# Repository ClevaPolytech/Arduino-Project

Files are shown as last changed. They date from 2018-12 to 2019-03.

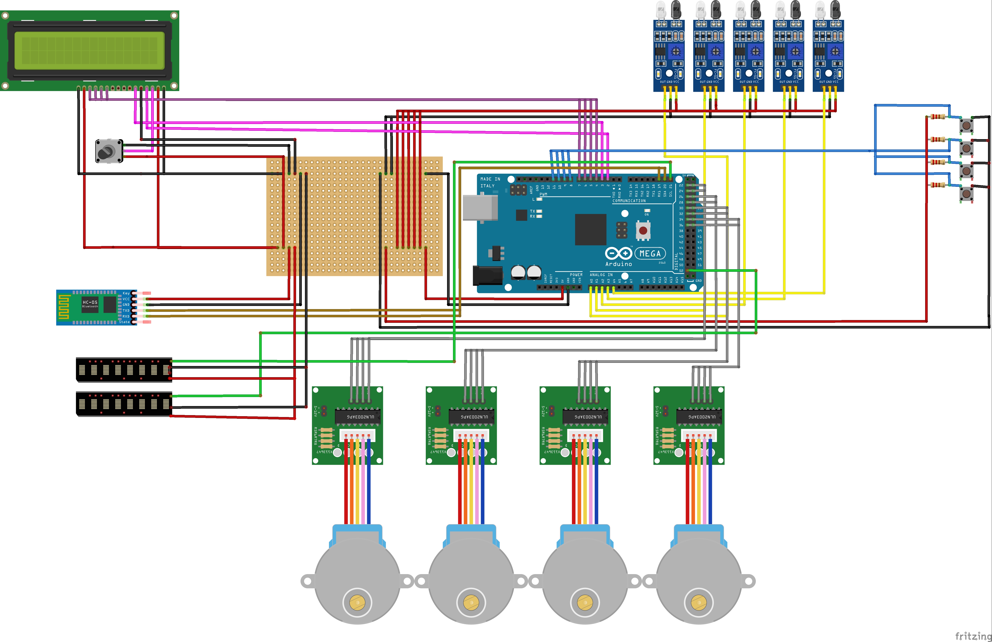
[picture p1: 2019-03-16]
CodesProjets/Montage/schemaFFcomplet.jpg

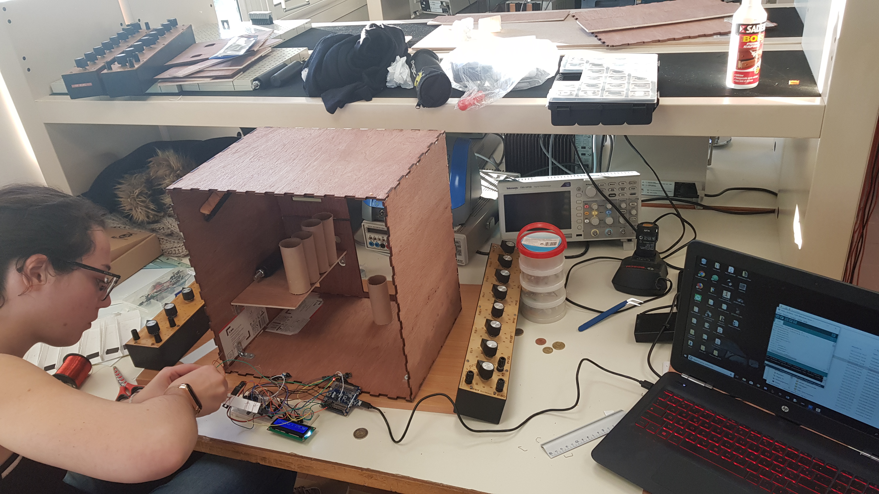
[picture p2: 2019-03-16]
Photos/20190107_161705.jpg

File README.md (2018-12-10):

## Welcome to GitHub Pages

You can use the [editor on GitHub](https://github.com/ClevaPolytech/Arduino-Project/edit/master/README.md) to maintain and preview the content for your website in Markdown files.

Whenever you commit to this repository, GitHub Pages will run [Jekyll](https://jekyllrb.com/) to rebuild the pages in your site, from the content in your Markdown files.

### Markdown

Markdown is a lightweight and easy-to-use syntax for styling your writing. It includes conventions for

```markdown
Syntax highlighted code block

# Header 1
## Header 2
### Header 3

- Bulleted
- List

1. Numbered
2. List

**Bold** and _Italic_ and `Code` text

[Link](url) and ![Image](src)
```

For more details see [GitHub Flavored Markdown](https://guides.github.com/features/mastering-markdown/).

### Jekyll Themes

Your Pages site will use the layout and styles from the Jekyll theme you have selected in your [repository settings](https://github.com/ClevaPolytech/Arduino-Project/settings). The name of this theme is saved in the Jekyll `_config.yml` configuration file.

### Support or Contact

Having trouble with Pages? Check out our [documentation](https://help.github.com/categories/github-pages-basics/) or [contact support](https://github.com/contact) and we’ll help you sort it out.

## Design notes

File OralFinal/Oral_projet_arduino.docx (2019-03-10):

Oral projet arduino

-Intro : Maev

-Qu’est-ce que c’est ?

D’où vient l’idée : idée de Maeva tirelire + volonté de clément de réaliser un objet utile, plus imposant.

C’est un distributeur de nourriture avec monnayeur intégré et ne rend pas la monnaie.

-Monnayeur

-Lumière/barre de chargement

-écran lcd pour les informations

- boutons de sélection

Objectifs

-pour but de faire un projet pas compliqué mais finissable, projet achevable dans le temps imparti.

-Nous souhaitons faire un distributeur automatique de petits objets. On se base sur le principe des distributeurs de nourriture, comme on peut en trouver un peu partout.

Comment va-t-on procéder :

• Faire la structure (une sorte de boîte de dimension : 30x40x40 (largeur, longueur, hauteur))

• Faire un monnayeur qui compte la monnaie (si jamais on a le temps on fait un rendu de monnaie)

• Un écran LCD qui indique la somme mise dans la machine

• Des boutons pour choisir l’objet

• Un système de « paiement par carte » qui reviendrait à envoyer une information par Bluetooth

- Un système de sécurité pour ouvrir la porte qui dévoile le mécanisme

• Une trappe qui s’ouvre pour pouvoir récupérer l’objet

En bonus (si on a le temps)

• Machine à café

• Rendre la monnaie

-Evolution chronologique :

1ere partie : du début –> assemblage de la boite

-1ere conception autodesk

-tube pq, récup les pièces

-découpe planche de bois

- monnayeur (pièce noire)

-fichier de découpe inkscape + découpe laser

-assemblage des planches

-ressort

Problèmes 1ere partie :

-écart face avant résolu par LED

- problème de dimension découpe laser

- tubes qui se détache

- rail trop grand découpé à plusieurs reprises

2e partie : assemblage boite ->peinture rouge

- Trou face avant, détails (pour l’écran, bouton, fente pièce, récup monnaie)
- Découpe laser FabLab des planches intérieures.
- Rail
- Piece polystyrène monnayeur
- Ecran LCD
- Capteur IR
- Peinture

Problèmes 2e partie :

- Capteur IR avec le soleil +code, solution scotch noir
- Dimensions trous boutons résolu par les LED
- Oubli de la porte donc découpe face avant +charnière.

3e partie : peinture -> fin

- Boutons + nouveaux trous
- Moteurs
- Pieces en bois entre le ressort et le moteur, calle ressort
- Nouvelles LED
- Bluetooth
- Le pvc tordu
- Soudure
- Optimisation
  - Nouveaux ressorts
  - Nouveau rail

Problèmes 3e partie :

- Problème pièce pvc douteuse
- Conception 3D
- Code Moteur
- Moteur bloqué par la pièce en bois, donc ne tourne pas -> solution : moyeux
- Toboggan pas de place

Planning

Planning programmé jusqu’au 14 janvier 2019, planning largement non tenu -> vrai planning

Conclusion

Remerciements

Aux enseignants : Mr Masson, Mr A

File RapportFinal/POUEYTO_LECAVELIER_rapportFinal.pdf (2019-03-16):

Département d partement d’ Electronique lectronique

# PROJETS ARDUINO – PEIP2

## Année scolaire 2018-2019

## Distributeur automatique alimentaire :

## Le PolyShop

### Etudiants : Clément POUEYTO, Maëva LECAVELIER

### Encadrants : Pascal MASSON, Nassim ABDERRAHMANE

Ecole Polytechnique Universitaire de Nice Sophia-Antipolis, Electronique avec ARDUINO 1645 route des Lucioles, Parc de Sophia Antipolis, 06410 BIOT

PeiP2-Electronique avec ARDUINO

### REMERCIEMENTS

Nous tenions à remercier Monsieur Pascal Masson, enseignant-chercheur à Polytech’Nice, pour sa disponibilité, sa patience, sa bienveillance, son investissement et ses conseils. Et, également, l’entreprise SYMES, bureau d’étude électronique à Cagnes sur Mer pour nous avoir prêté leur imprimante 3D. Nous remercions aussi Marc Forner pour son aide lors de nos venues au FabLab.

## SOMMAIRE

## Introduction

Durant cette deuxième année en PeiP de Polytech’Nice, nous avons dû réaliser un projet avec la carte Arduino. Ce projet avait pour but de nous apprendre à créer et à s’adapter aux difficultés que l’on peut rencontrer dans l’élaboration d’un tel objet. Il visait aussi à l’apprentissage et au perfectionnement de l’utilisation des différents outils et logiciels.

Nous avons décidé de faire un distributeur de petits snacks (type Snickers, Tictac, chewing-gum etc…). Ce distributeur prend les pièces de 10cts à 2€, trie les pièces, et distribue de la nourriture. Il ne rend pas la monnaie.

Voici notre projet à l’écriture de ce rapport :

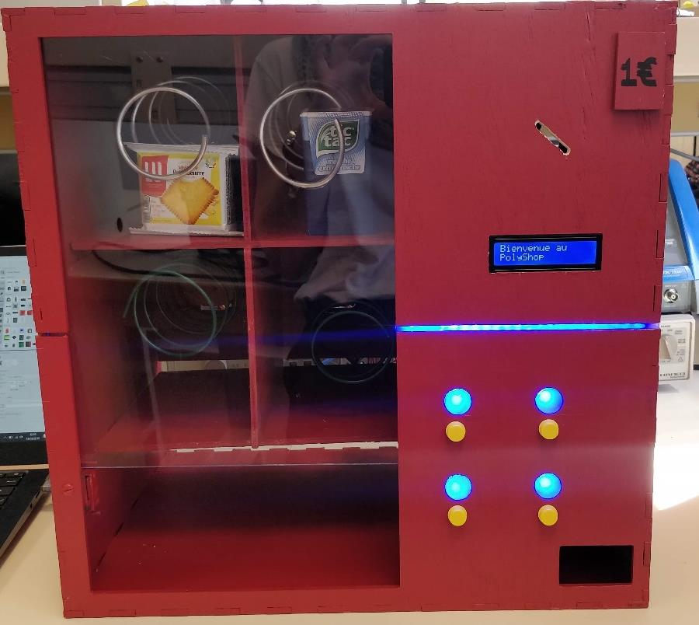
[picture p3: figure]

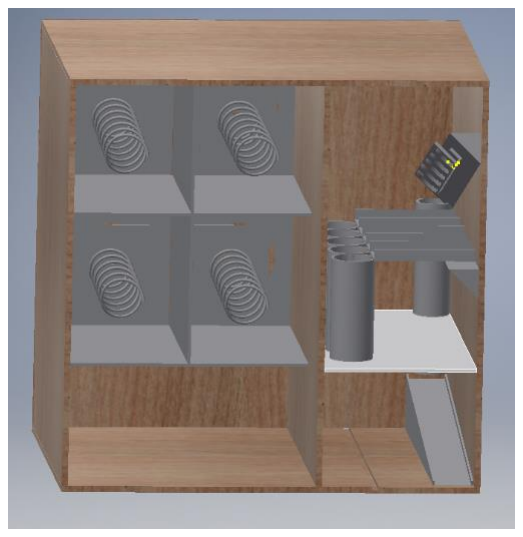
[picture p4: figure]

Fichier 3D sans la façade avant

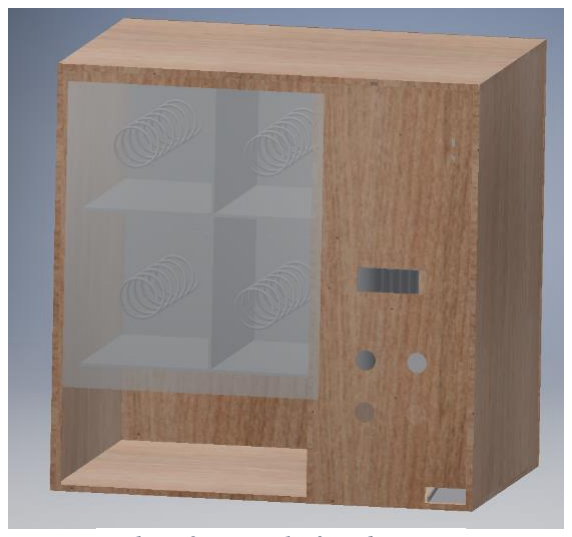
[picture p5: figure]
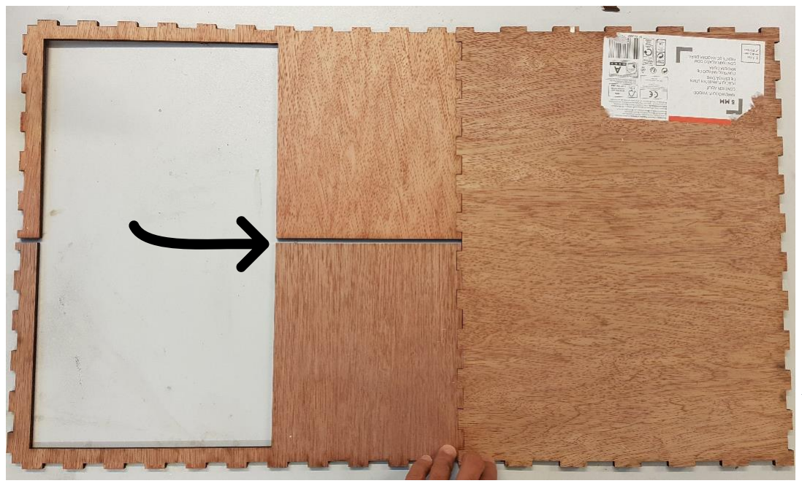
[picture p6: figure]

Planche 40*40 fixée à la planche adjacente. On voit la fente qui pose un problème.

# Chapitre I : La construction du distributeur

### I.1 La modélisation 3D

Dès le début du projet, nous avons représenté en 3D notre objet pour visualiser ce que nous souhaitions. Cette étape nous a permis d’avoir les dimensions de toutes les pièces et planches que nous allions avoir besoin. Le logiciel utilisé est Autodesk Inventor.

Pour ce faire, nous
réalisons les pièces une par
une | pour | ensuite | les
assembler. Certaines pièces ne sont pas forcément bien assemblées avec les autres,
mais | ce | fichier | a
uniquement pour but de
nous renseigner sur les
dimensions, l’agencement et les pièces nécessaires. Cela a été le fil rouge de notre projet.

### I.2 La découpeuse laser et Inkscape

Pour découper les planches extérieures de notre projet, nous avons utilisé une découpeuse laser. Il était nécessaire d’utiliser cet outil, car la découpe devait être précise pour que l’on puisse bien assembler la boîte. Nous nous sommes alors initiés à Inkscape, logiciel professionnel de dessin vectoriel libre et gratuit. Pour représenter notre projet, nous utilisons l’extension Box Maker, téléchargeable depuis le site du logiciel.

Le premier problème que l’on a rencontré était la dimension des planches que l’on peut découper dans la découpeuse laser. Elle n’accepte que des planches de 30*60 cm alors que l’on doit couper des planches de 40*40 cm. Pour réussir malgré cet obstacle, nous avons dû découper les grandes planches en deux fois. Mais un autre problème est survenu, il y avait une fente au milieu lorsque nous avons regroupé toutes les planches. Illustration :

Fichier 3D avec la façade avant

Guirlande de LED intérieur

Guirlande de LED vue de l’extérieur

Notre projet une fois que
les | planches | sont
découpées et assemblées
(non collées encore)

On a résolu ce problème plus tard en mettant une guirlande de LED et une fine plaque de plexiglass gravée à la découpeuse laser pour diffuser la lumière.

Les autres découpes faites avec Inkscape et la découpeuse laser sont celles des trous de la face avant. Il faut des trous pour mettre l’écran, les boutons, la pièce de monnaie et récupérer la monnaie.

La fente pour les pièces de monnaie

La fente pour l’écran LCD

La fente pour les boutons. A cause d’une erreur lors de l’édition du fichier, les trous sont trop grands, pour résoudre le problème on a fixé des ronds de plexiglass gravé avec des LED derrière. Puis, nous avons repercé pour avoir des trous de la bonne dimension.

Le trou pour récupérer les pièces, mais finalement nous n’avons pas eu le temps de faire un système de rendu de monnaie.

### I.3. Les autres pièces

### I.3.1 Les planches internes

Il faut faire des petites planches intérieures qui vont servir à séparer la partie système et visible, supporter la carte Arduino ou encore délimiter les compartiments des différents aliments. Pour celles-ci, nous avons recyclé les chutes des grandes planches et les avons découpées à la scie sauteuse. Pour les fixer, nous avons utilisé de la colle à bois. De plus, les dimensions étaient faites de telle manière que la planche soit serrée entre les grandes planches, comme ça, il était plus facile de coller.

Solution pour mettre les boutons

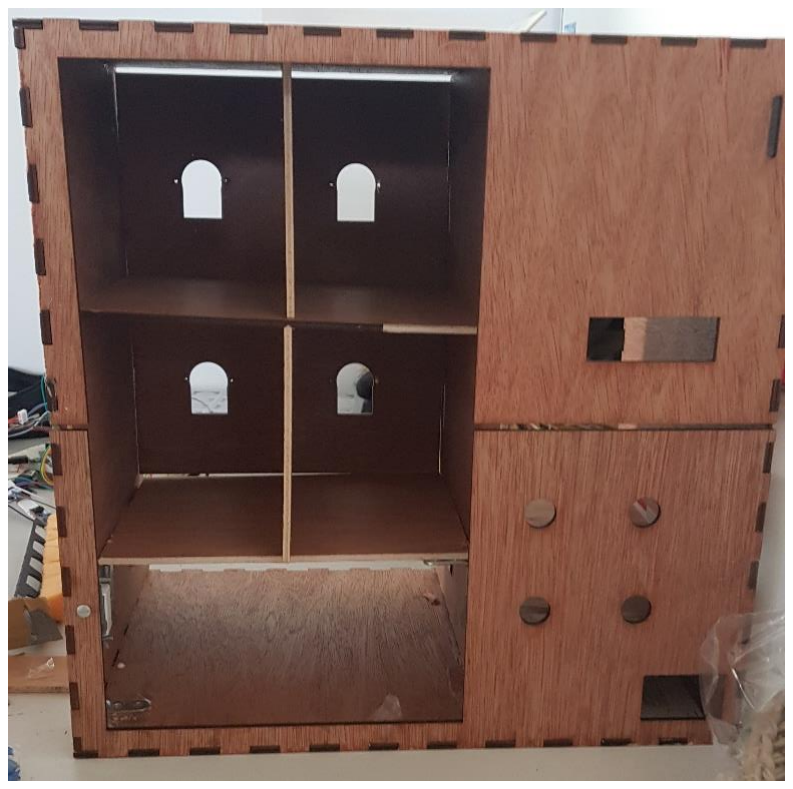
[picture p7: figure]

Vue de face. Derrière les trous il y a la planche qui tiendra le système.

Pour fixer correctement les moteurs, Inkscape nous a encore été utile. Nous avons pris une planche et dedans on a découpé la forme des moteurs. Ce qui donne :

### I.3.2. Le système de tri de pièces

I.3.2.a. Trier les pièces.

Pour réaliser cette partie, on a cherché des idées sur internet. Le tri selon la taille paraissait le meilleur compromis. Donc, nous sommes partis sur cette idée. Mais il y avait une contrainte au niveau de la taille de notre trieur, il ne fallait pas qu’il soit trop long ni trop large. On s’est alors dit que l’on pouvait trier selon le diamètre. A partir d’Autodesk Inventor encore, nous avons modélisé cette pièce :

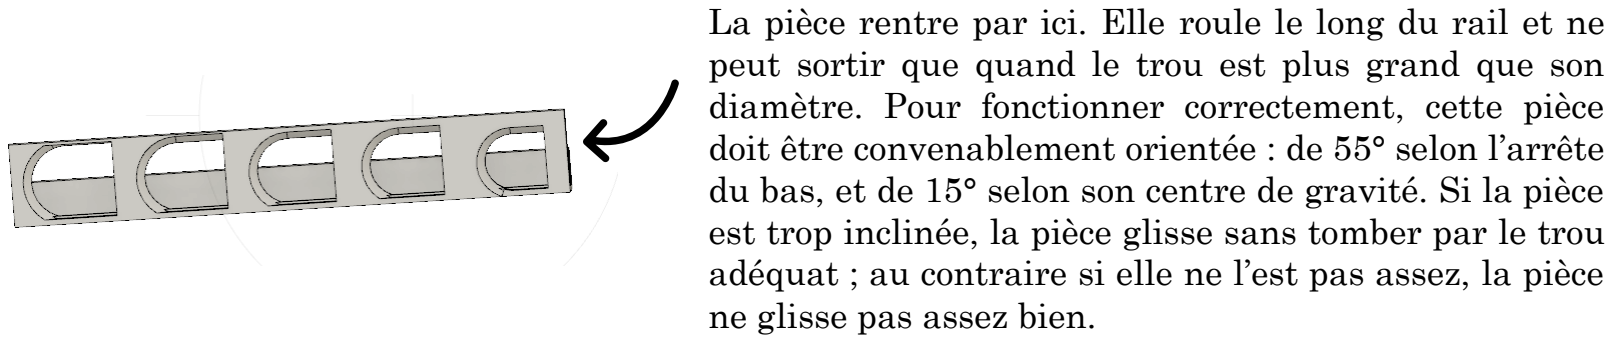
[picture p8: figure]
ne glisse pas assez bien.

Une fois que les pièces sont correctement triées, elle glisse le long d’un rail. Ce rail, d’abord réalisé en bricolant, a été ensuite modélisé et imprimé en 3D. Le système de détection sera expliqué plus tard.

La pièce rentre par ici. Elle roule le long du rail et ne peut sortir que quand le trou est plus grand que son diamètre. Pour fonctionner correctement, cette pièce doit être convenablement orientée : de 55° selon l’arrête du bas, et de 15° selon son centre de gravité. Si la pièce est trop inclinée, la pièce glisse sans tomber par le trou adéquat ; au contraire si elle ne l’est pas assez, la pièce

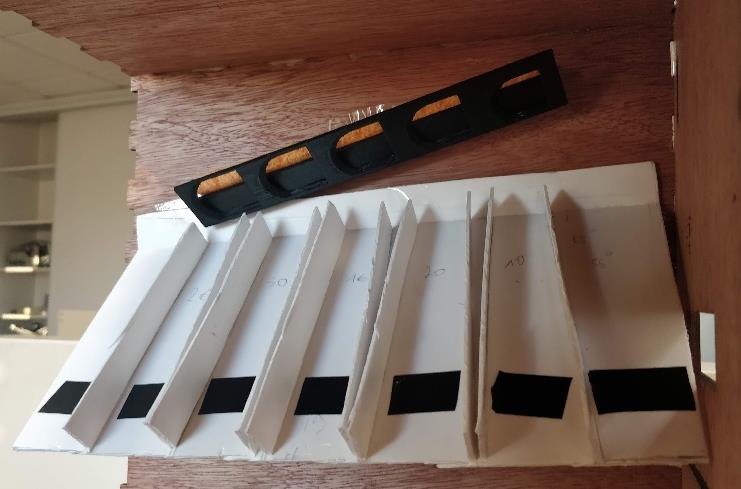
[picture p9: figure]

Ancien modèle en PVC et tenu par du scotch, et trieuse indépendante, correctement fixée grâce à du polystyrène.

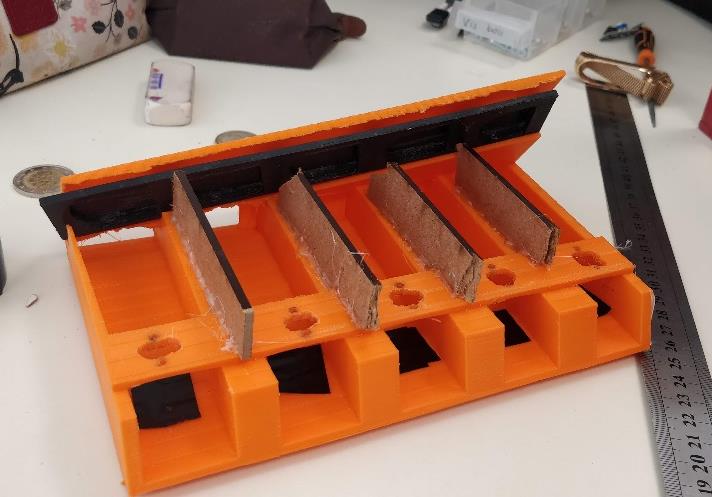
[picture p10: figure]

Nouveau modèle, en 3D, avec support pour la trieuse et pièce en bois pour séparer les compartiments. Elle est surélevée par la suite grâce à des pieds en bois.

I.3.2.b. Stocker les pièces.

Initialement, le stockage des pièces était prévu pour pouvoir rendre la monnaie plus facilement. Mais nous n’avons pas pu développer cette fonctionnalité. Cependant, nous voulons tout de même stocker nos pièces. Le problème est qu’il ne reste plus beaucoup de place dans le compartiment système, et qu’avec
tous les câbles que nous aurons, il sera difficile de retirer
des grosses pièces… Au début, nous avons découpé un tube
en carton en plusieurs petits tubes qui récolteront les pièces. Mais finalement, ceux-ci étaient trop difficiles à
utiliser | correctement | (pour | les | raisons | citées
précédemment), nous avons abandonné l’idée de ces tubes.

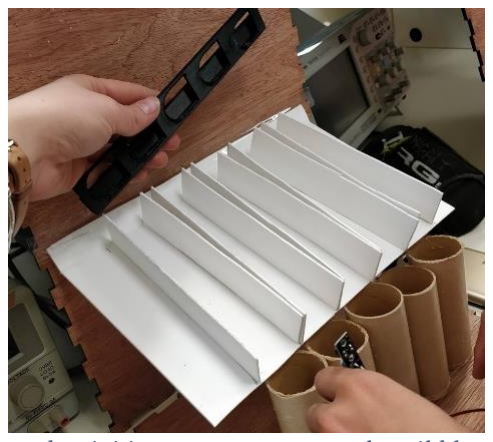
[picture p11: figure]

Comme le rendu de pièce semblait impossible, l’idée d’un rail qui faisait glisser les pièces jusqu’à un récipient, sans séparer les différentes pièces de monnaie, était bien. Mais nous n’avons pas eu le temps d’explorer convenablement cette piste.

### I.4 La distribution des produits

I.4.1. Les vis sans fin.

Comme dans les « vrais » distributeurs, il nous fallait un système de vis sans fin pour faire tomber le produit.

Au début, nous utilisions du fil métallique plastifié que nous avions entouré autour d’une bouteille. Mais, ces vis étaient trop souples, se tordaient, et étaient relativement lourdes. Alors, nous avons
remplacé | le | fil | métallique | par | de
l’aluminium. C’est plus difficile à tordre, mais plus solide et léger. Pour le tordre, nous l’avons enroulé autour d’un tube PVC dans lequel nous avions fait un petit trou pour maintenir la tige en alu.

Les tubes initiaux se trouvent sous le rail blanc.

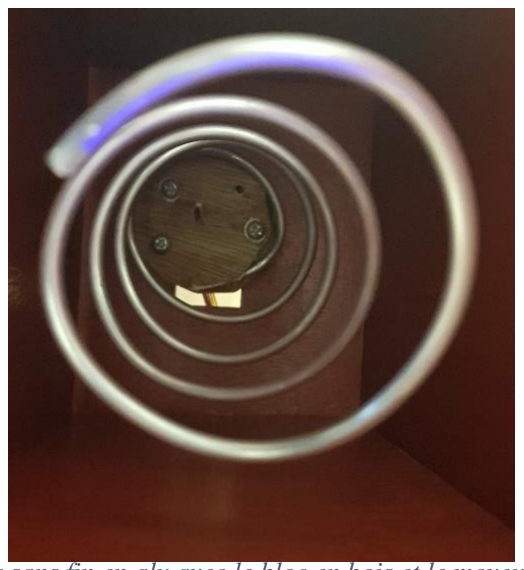
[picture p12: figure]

Vis sans fin en alu avec le bloc en bois et le moyeu (derrière la pièce ronde en bois) fixés au moteur.

I.4.2. Liaison vis-moteur.

Après avoir réalisé les vis sans fin, il faut les relier au moteur. Pour cela, nous avons pris du bois, découpé en rond, puis nous avons « encadré » le bout de la vis sans fin entre deux planches rondes et les avons vissées entre elles pour que ce soit bien fixé. Pour accrocher ce système, nous avons fait un trou de la taille de l’axe du moteur pour pouvoir glisser les vis sans fin dessus. Mais nous avons rencontré plusieurs problèmes :

Les vis utilisées gênaient à la rotation de la pièce en bois : les vis frottaient et le bloc vis+rond en bois tombait.

Après avoir résolu ce premier problème en creusant légèrement dans le bois, le bloc vis+rond tombait tout seul à cause du poids de ce dernier et des mouvements des vis souples.

La seule solution est d’installer des moyeux, pièce qui se coince au moteur grâce à une vis de serrage et qui vient se visser correctement au bloc. Mais leur installation est longue : environ 1h par vis. Donc, actuellement, nous n’en avons qu’un seul d’installé, mais plus tard il faudra couper autour de chaque moteur pour sortir tout le bloc et installer le moyeu en aillant plus de place.

I.5. La façade.

I.5.1. Peinture et personnalisation.

Pour rendre notre distributeur plus beau et cacher les étiquettes et les imperfections du bois, nous avons peint notre projet. Nous voulions une couleur rouge plus ou moins métallisé, mais la peinture que nous avons eu été un rouge basque (un rouge qui tend légèrement vers le rose). Nous avons fait 2 couches de peinture presque partout, sauf dans les endroits difficilement atteignables.

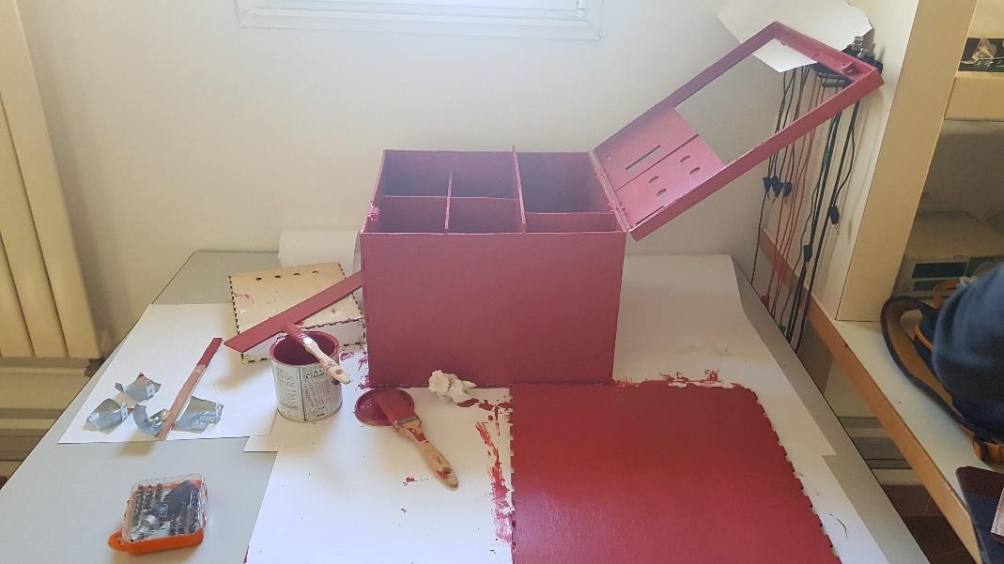
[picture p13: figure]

I.5.2. La vitrine.

En fixant nos planches, nous nous sommes aperçus que nous avions oublié de faire une porte… Mais grâce à l’outil multifonction, on a découpé la porte comme sur la photo au-dessus. Pour permettre de faire une vraie porte, nous avons vissé des charnières sur les côtés et un aimant de l’autre côté pour que la porte soit maintenue fermée.

Après la peinture, on a fixé une vitre en plexiglass grâce à des vis. Ainsi, notre distributeur a un peu plus de charme.

Petit détail : on a caché la première fente (qui n’était plus utilisable avec le nouveau rail en 3D) avec un bout de bois qui indique le prix.

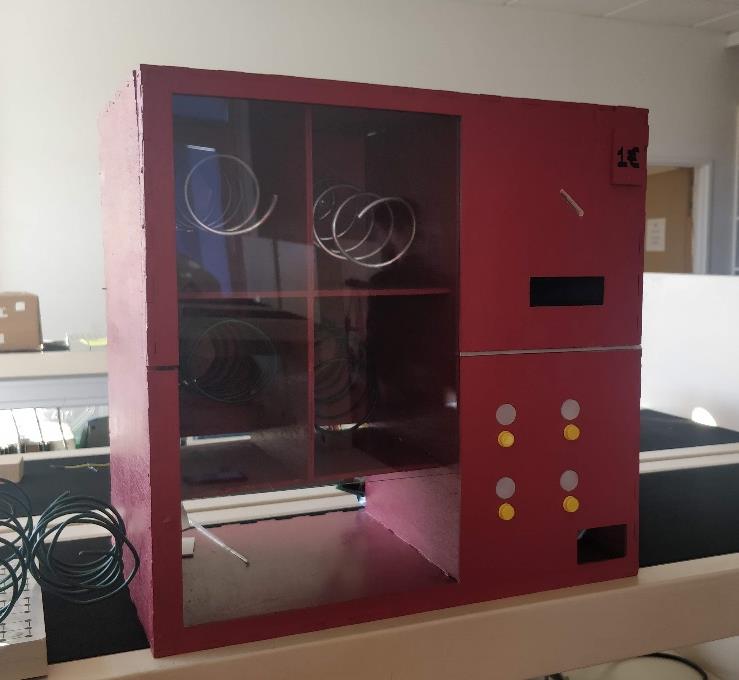
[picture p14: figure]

### I.5.2. Le visuel : les LED

Pour combler les différentes erreurs qu’on a faites lors de la construction, nous avons eu l’idée de les cacher avec des LED. De plus, la guirlande de LED sert de barre de chargement, et d’indicateur si on appuie sur un bouton alors que la mauvaise somme est entrée. La LED des boutons permet de savoir très rapidement si l’achat est validé ou non.

La boîte après la première couche, en train de sécher.

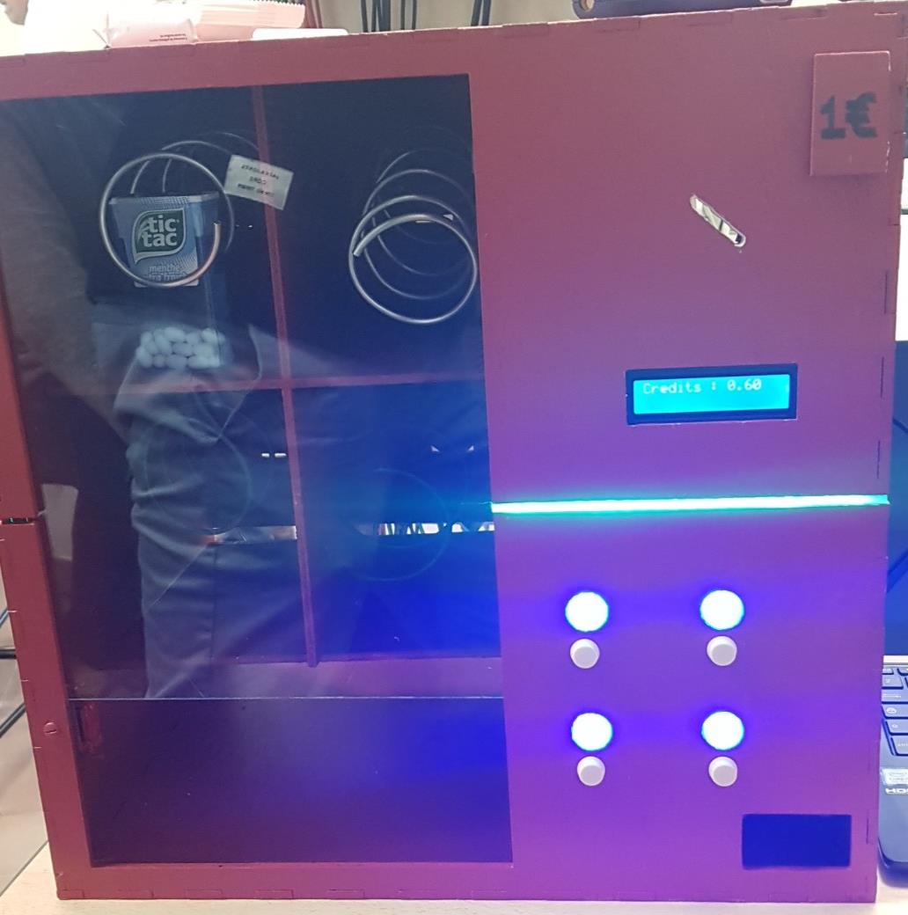
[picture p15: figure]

Les LED participent à une interface utilisateur plus agréable.

Les LED au niveau des boutons viennent d’une erreur de manipulation du logiciel Inkscape. Les trous que l’on a découpés étaient trop grands, et donc les boutons ne pouvaient pas loger dedans. Du plexiglass gravé à la découpeuse laser a encore une fois permis de cacher ces erreurs.

Chapitre II : Electronique et algorithmie.

### II.1. Vision globale des modules

Le distributeur est constitué de plusieurs modules :

- Les capteurs InfraRouge (IR) : détectent les pièces.
- L’écran LCD : sert d’interface utilisateur.
- Les boutons : permettent le choix du produit.
- Les moteurs pas-à-pas : permettent de faire tomber le produit.
- Bluetooth : permet de payer sans contact

Voici le schéma du montage complet :

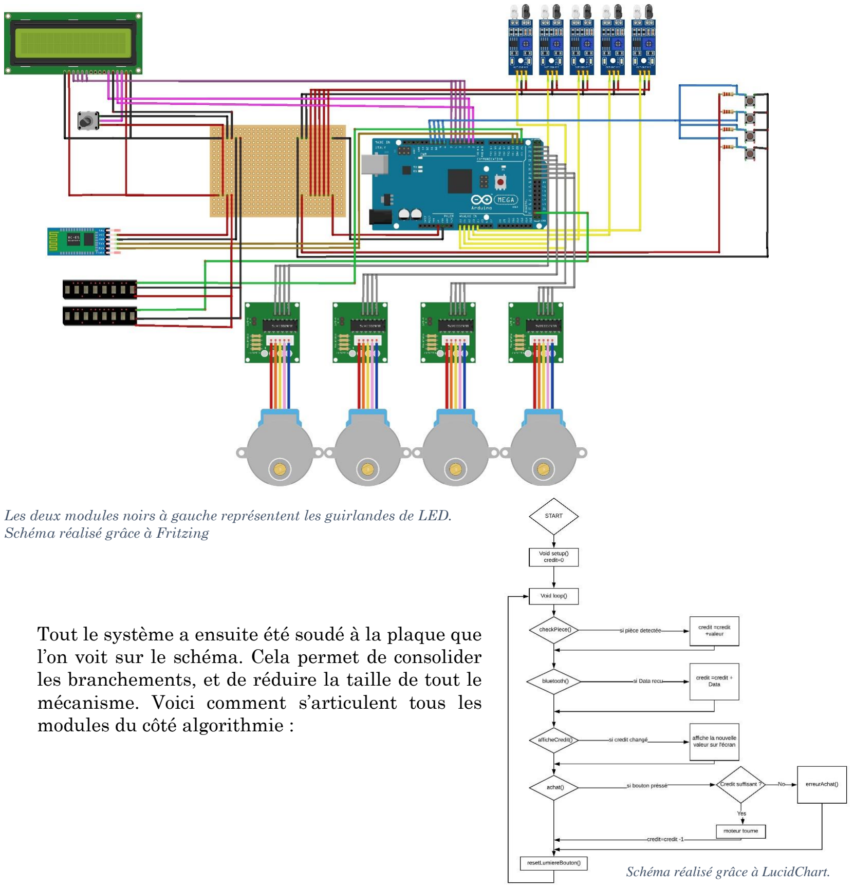
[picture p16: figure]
modules du côté algorithmie :; Schéma réalisé grâce à Fritzing; Schéma réalisé grâce à LucidChart.

Tout le système a ensuite été soudé à la plaque que l’on voit sur le schéma. Cela permet de consolider les branchements, et de réduire la taille de tout le mécanisme. Voici comment s’articulent tous les

Les deux modules noirs à gauche représentent les guirlandes de LED.

II.2. La détection des pièces.

Schéma du montage pour la détection des pièces :

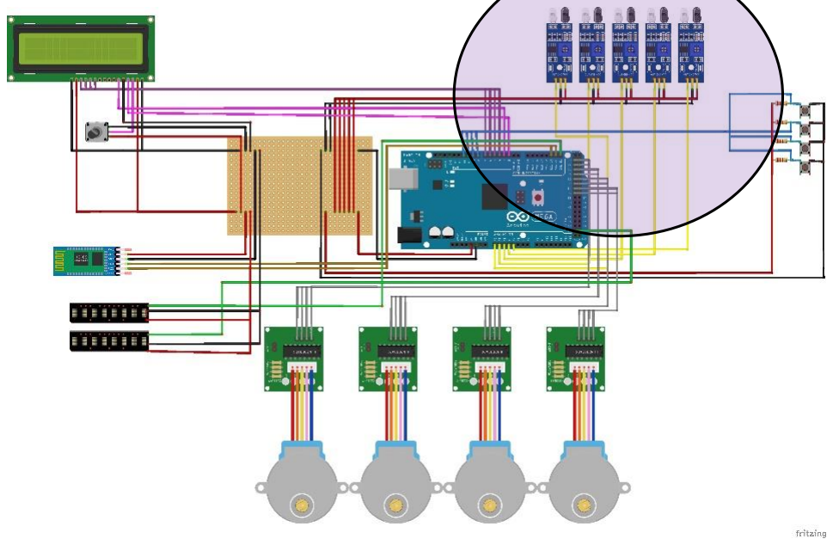
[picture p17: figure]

Les détecteurs IR sont fixés sur le rail qui fait glisser les pièces. Ils sont fixés grâce à des vis, et la tête IR est orientée vers le rail. Un scotch noir sur ce dernier permet de ne pas renvoyer le rayon envoyé par le capteur. Voici à quoi ressemble donc la partie physique :

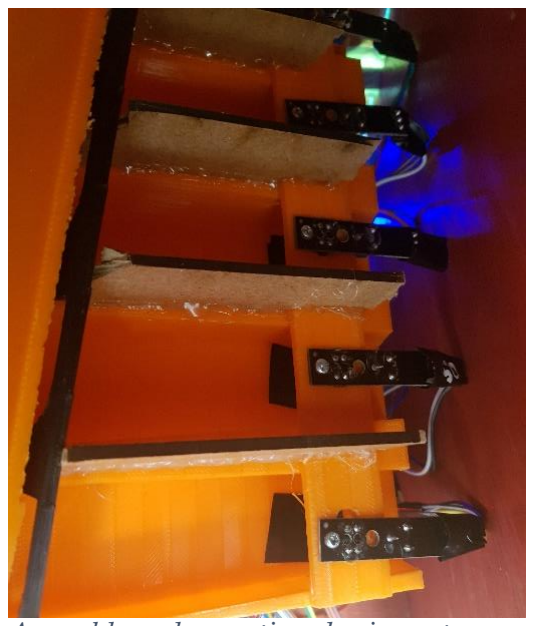
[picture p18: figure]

Les fils sont placés de cette façon pour ne pas gêner les pièces lors de leur chute.

Il y a des trous de la taille de la tête IR et deux petits trous qui coïncident avec les trous du module IR. Nous n’avons fixé qu’une vis car cela suffisait.

Au niveau algorithmique, c’est une boucle « for » qui parcourt toutes les X millisecondes un capteur par un capteur (la boucle est suffisamment rapide pour capter toutes les pièces qui peuvent passer). Lorsqu’une pièce est détectée, cette boucle s’arrête pendant 1 seconde, pour éviter de capter plusieurs fois la même pièce. Lorsqu’un détecteur est déclenché, il incrémente une variable « crédit » qui compte l’argent courant.

Assemblage des parties physique et electronique.

I.3. L’interface utilisateur.

Schéma du montage de l’interface utilisateur (écran LCD) :

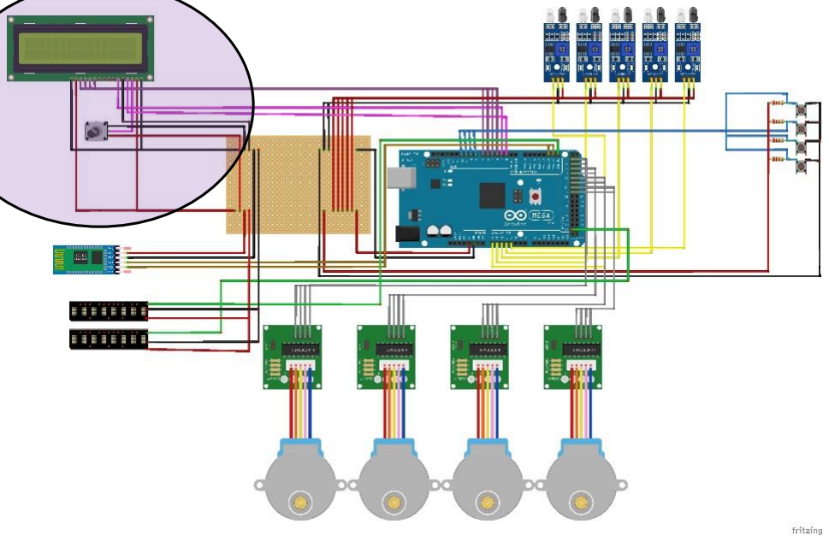
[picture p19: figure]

Pour l’interface utilisateur, on a utilisé un simple écran LCD qui affiche les informations principales. Différent cas :

Message d’accueil

Lorsqu’on appuie sur un bouton mais qu’il n’y a pas assez d’argent.

Après un achat. Une fois que l’objet est tombé.

Affiche le crédit courant.

D’un point de vue algorithmique, l’écran ne fait qu’afficher la variable « crédit » ou la valeur « prix objet – crédit ». L’affichage se réinitialise seulement lors d’une requête Bluetooth (sinon, il pouvait y avoir conflit entre les bibliothèques Adafruit (pour les LED) et timer).

II.4. Le choix du produit.

Schéma du montage des boutons :

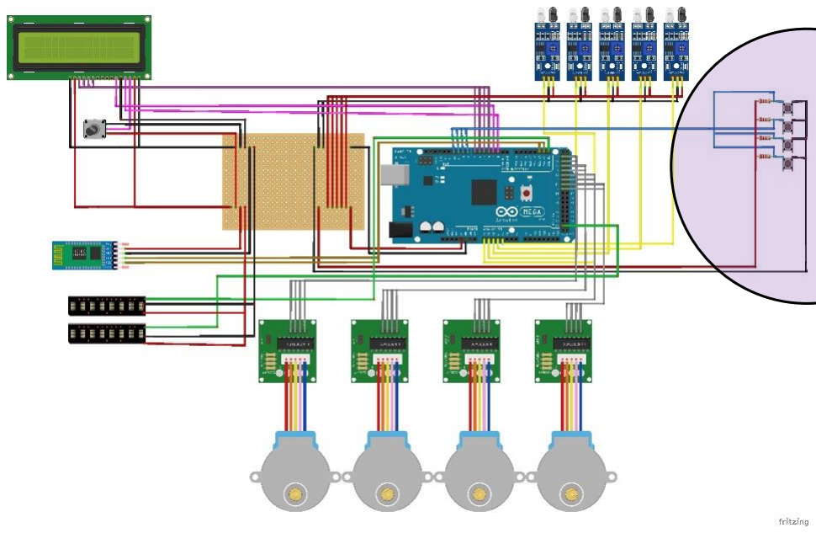
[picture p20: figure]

Les boutons sont fixés dans leur emplacement grâce à de la colle en pistolet, puis maintenus en plus grâce à du scotch. Ce maintien est indispensable, car il faut que le bouton reste en place lorsque l’on appuie dessus.

L’algorithmie derrière est très basique. L’appui sur le bouton envoie une information à la carte, qui vérifie qu’il y ait assez d’argent rentré avant d’envoyer un message au moteur.

II.5. Les moteurs.

Schéma du montage des moteurs :

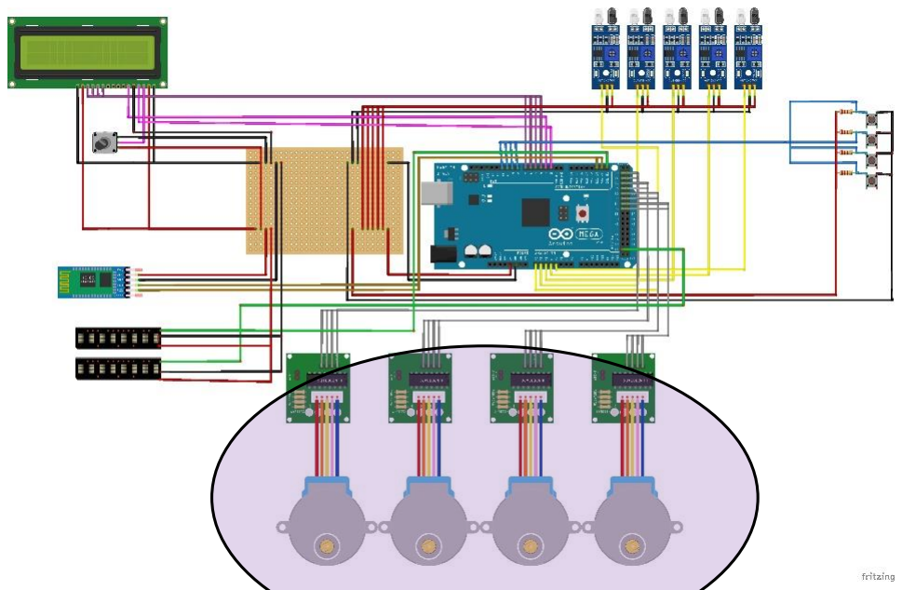
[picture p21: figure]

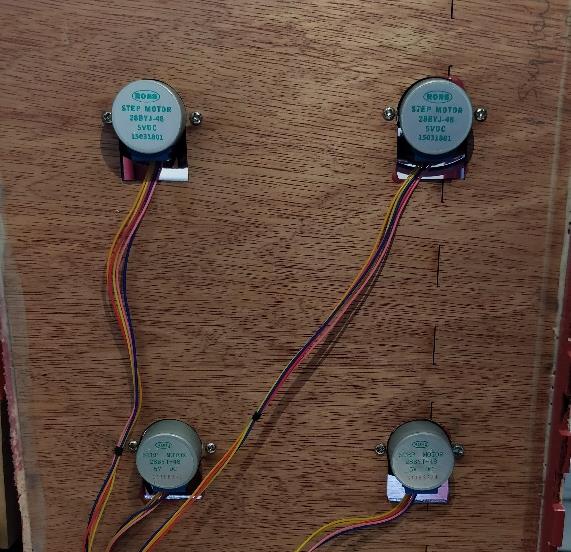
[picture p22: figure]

Les moteurs tournent d’un tour dans le sens des aiguilles d’une montre. Ainsi, le produit peut avancer et tomber. On utilise des moteurs pas-à-pas 5V, qui sont fixés à l’arrière du distributeur par des vis, sur une planche découpée avec la forme des moteurs à la découpeuse laser.

D’un point de vue algorithmique, les moteurs tournent grâce à une boucle qui tourne 512 fois pour réaliser un tour complet.

Lorsque les moteurs tournent, une autre fonction est appelée qui créer une barre de chargement au niveau de la barre de LED en façade.

II.6. Le module Bluetooth.

Voici le montage du module Bluetooth :

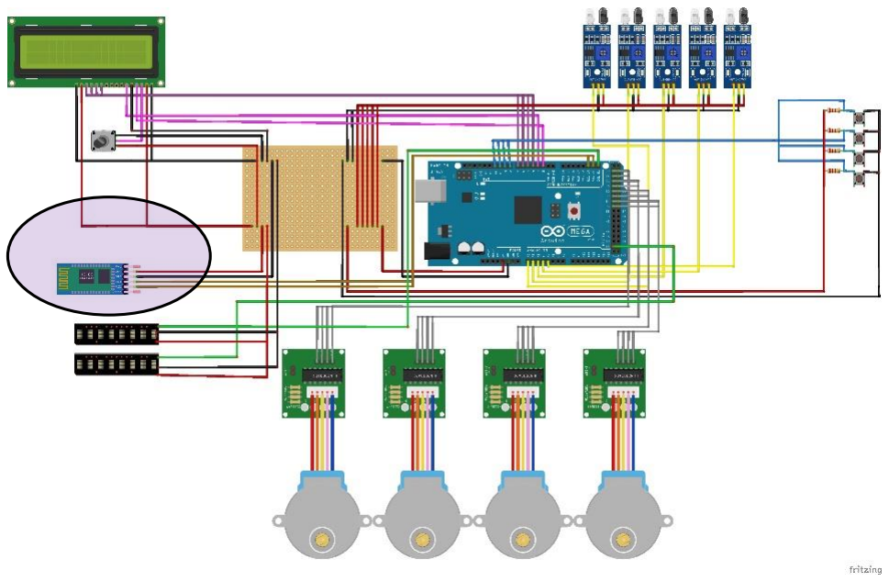
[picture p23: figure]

Ce module permet de communiquer sans fil avec le distributeur. La fonctionnalité qu’on a faite est assez basique. Elle permet d’incrémenter la variable « crédit », via un bouton sur le smartphone. Nous n’avons pas fait en sorte de pouvoir « appuyer sur le bouton », car c’est plus naturel de devoir être à côté de la machine lorsqu’on achète un produit.

L’interface Bluetooth est comme ceci :

L’algorithme est simple. Chaque bouton envoie une information avec une lettre en premier caractère. Le bouton pour ajouter 2€ envoie une information du type « A*** », celui de 1€ « B*** » etc… Donc, selon la première lettre, la variable « crédit » est incrémentée de la somme correspondante. Il y a également le bouton « réinitialisation » (en haut à gauche) qui réinitialise le crédit à 0, et relance le setup de l’écran pour qu’il affiche

le texte de bienvenue.

Arrière du projet

Chapitre III : Recul et perspective.

III.1. Cahier des charges et comparaison.

Initialement, nous avions prévu de faire la structure telle qu’on l’a faite, un système qui compte la monnaie, un écran LCD qui sert d’interface, un système de sélection de produits, un mécanisme de sécurité pour ouvrir le distributeur qu’aux personnes autorisées, un moyen pour payer sans fil (simuler un paiement par carte) et enfin une trappe qui permettrait de récupérer les objets, comme celle que l’on peut trouver sur les distributeurs habituels.

Finalement, nous avons bien eu le temps de faire la structure telle qu’on la souhaitait. C’est-à-dire des dimensions de 30*40*40 cm. Au début nous voulions le faire plus grand, mais cela aurait causé des problèmes pour faire tenir toutes les planches entre elles à cause du poids et de la longueur.

Le monnayeur a aussi été fait. Il est constitué du rail orange, qui sert à maintenir la trieuse (pièce noire), la pièce maîtresse du système de tri. Enfin, les capteurs IR terminent le monnayeur car c’est eux qui reconnaissent quand une pièce de monnaie est insérée. Le point à améliorer est le fait que nous n’ayons pas trouvé de système efficace pour récupérer et stocker les pièces. Pour le moment, elles tombent sur les câbles et sont difficiles à récupérer. Au début, nous avons mis des tubes en carton, mais ceux-ci étaient trop gros et fragile. Nous avons donc pensé à utiliser une planche de téflon ou plexiglass qui servirait de toboggan pour mener les pièces jusqu’à une boîte réceptrice.

Ensuite, pour ce qui est de l’interface utilisateur et du choix des produits, nous avons fait comme nous avions convenu. Cependant, les boutons ne sont pas encore tout à fait solides, puisqu’il arrive que parfois en appuyant dessus, ceux-ci s’enfoncent dans la structure plutôt que de s’activer.

Le système de paiement par carte s’est fait grâce au module Bluetooth. Au début, nous voulions faire tourner les moteurs également grâce à l’application, mais finalement, il s’est avéré qu’il était plus pratique et conventionnel d’appuyer sur le bouton physique pour déclencher le moteur.

Pour ce qui est du système de sécurité et de la trappe, ce sont deux points que nous n’avons pas pu traiter.

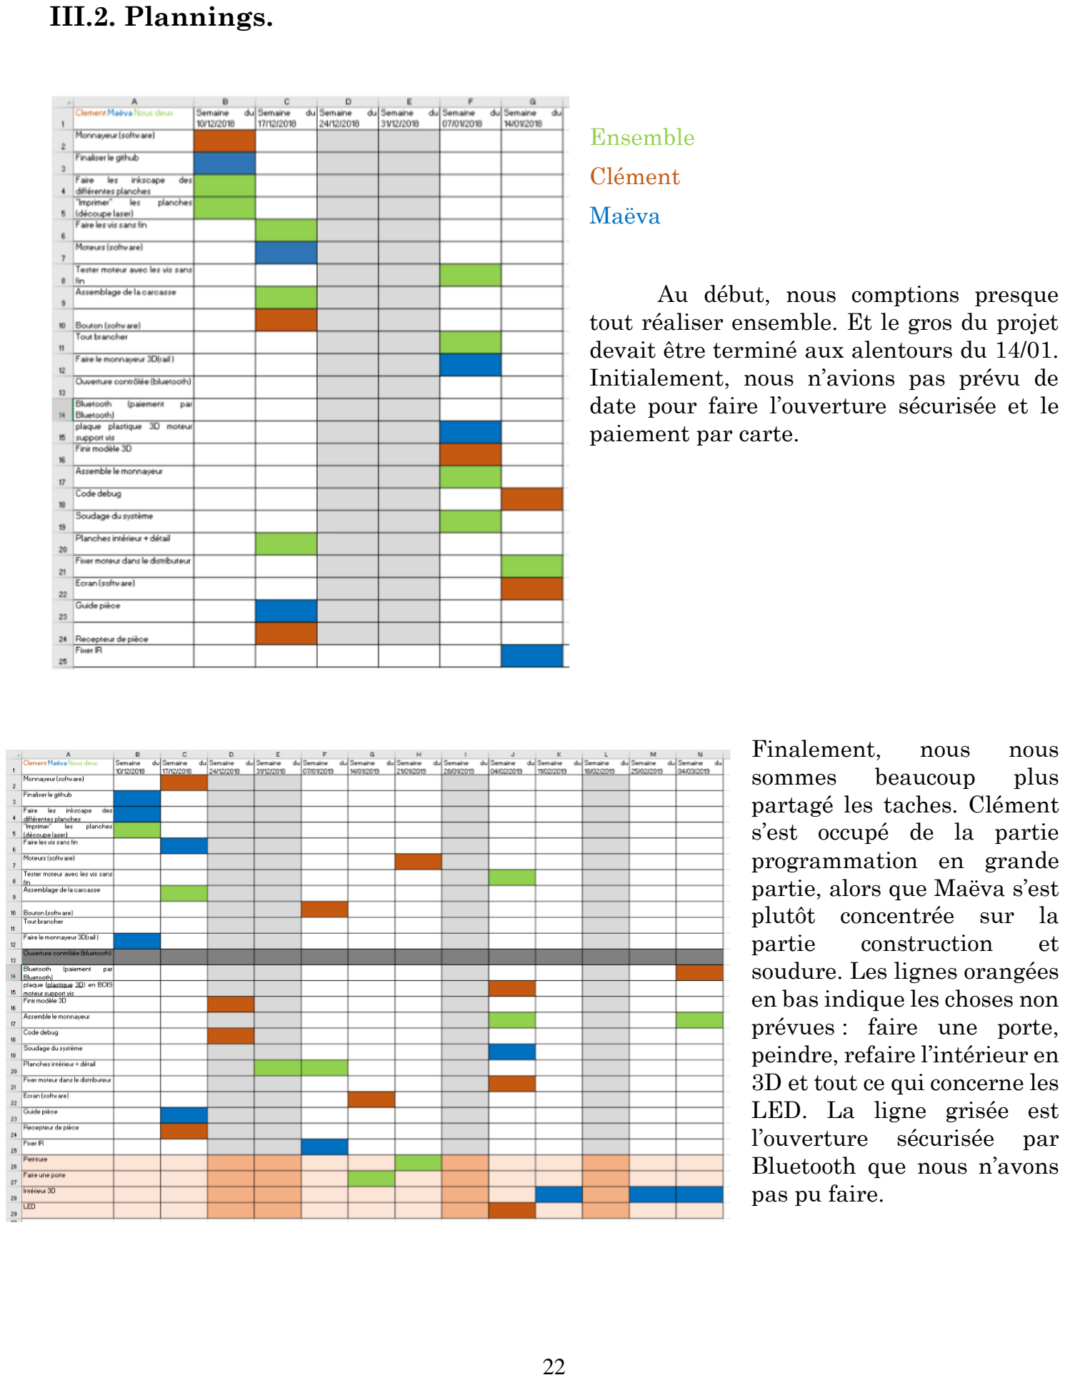
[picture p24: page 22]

III.2. Plannings.

Ensemble

Clément

Maëva

Au début, nous comptions presque tout réaliser ensemble. Et le gros du projet devait être terminé aux alentours du 14/01. Initialement, nous n’avions pas prévu de date pour faire l’ouverture sécurisée et le paiement par carte.

Finalement, | nous | nous
sommes | beaucoup | plus
partagé les taches. Clément s’est occupé de la partie
programmation en grande
partie, alors que Maëva s’est plutôt concentrée sur la
partie | construction | et
soudure. Les lignes orangées en bas indique les choses non prévues : faire une porte, peindre, refaire l’intérieur en 3D et tout ce qui concerne les LED. La ligne grisée est
l’ouverture | sécurisée | par
Bluetooth que nous n’avons pas pu faire.

### III.3. Perspective

Les fonctionnalités de la trappe et du système d’ouverture sécurisée sont des points majeurs qu’il faudra traiter dans le futur. Ces fonctionnalités permettraient de rendre l’appareil plus sûr et de pouvoir l’utiliser comme un « vrai » distributeur.

Il y avait aussi d’autres caractéristiques que le projet aurait pu avoir. Ce sont celles de rendre la monnaie (indispensable de nos jours). Et aussi le rendre plus pratique en ajoutant une machine à café, un système de déplacement pour qu’il vienne à nous… Des idées pas forcément naturelles mais qui peuvent être intéressantes.

Pour le rendu de monnaie, nous avions pensé à faire un système de trappe dans les tubes qui stockaient les pièces. Mais comme nous n’avons pas gardé ces tubes, nous n’avons pas approfondi ce point-là.

Il faudra aussi changer toutes les vis sans fin par de l’alu, et fixer les moyeux à chaque moteur. Nous n’avons pas pu le faire par manque de moyen et de temps.

Si ce projet devait être réutilisé, ce serait bien de changer les moteurs aussi, ceux-ci ont pu montrer des signes de faiblesse par moment : il arrivait qu’ils ne tournent plus lorsqu’ils étaient branchés depuis trop longtemps.

Un autre problème qui nous est arrivé, et qui devra être résolu si ce projet est approfondi, est au niveau de l’affichage LCD. Parfois, il écrivait des caractères inconnus. On ne sait pas si cela vient d’un faux contact ou d’un problème dans le code qui peut parvenir parfois.

# Conclusion

Ce projet s’est construit en trois étapes : la construction, l’algorithmie et l’optimisation. La construction regroupe tout ce qui concerne la création de la boîte, les planches intérieures, les découpes laser etc… La programmation derrière ce projet est assez simple, mais l’enjeu était de rendre la machine fluide et fonctionnelle quelques soient les conditions d’utilisation.

Dans l’optique où quelqu’un reprendrait le projet, il faudra finir les optimisations. C’est-à-dire remplacer les vis sans fin pour les faire en alu, et fixer les moyeux aux moteurs.

Pour améliorer ce projet, il faudrait faire un système de rendu de monnaie, une porte avec ouverture sécurisée et une trappe pour pouvoir récupérer les objets.

Tous les modules fonctionnent correctement ; mis à part par moment les moteurs qui ne tournent plus ou l’écran qui affiche des caractères inconnus.

# Bibliographie

Sources utilisées :

- https://www.arduino.cc/ : pour savoir comment fonctionne et se branche les modules
- http://users.polytech.unice.fr/~pmasson/Enseignement.html : pour les cours et les codes basiques.
- http://fritzing.org/home/ : pour le schéma du montage
- https://www.adafruit.com/ : pour la guirlande de LED et son fonctionnement
- https://howtomechatronics.com/projects/diy-vending-machine-arduino-based-mechatronics-project/ (https://howtomechatronics.com/projects/diy-vending-machine-arduino-based-mechatronics-project/) : idée de base

# Annexe

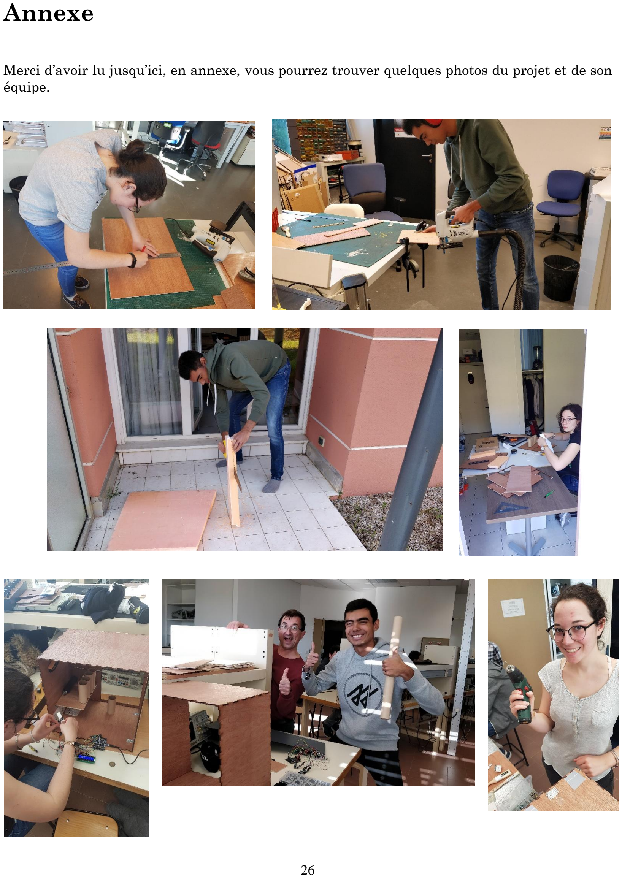
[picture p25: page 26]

Merci d’avoir lu jusqu’ici, en annexe, vous pourrez trouver quelques photos du projet et de son équipe.

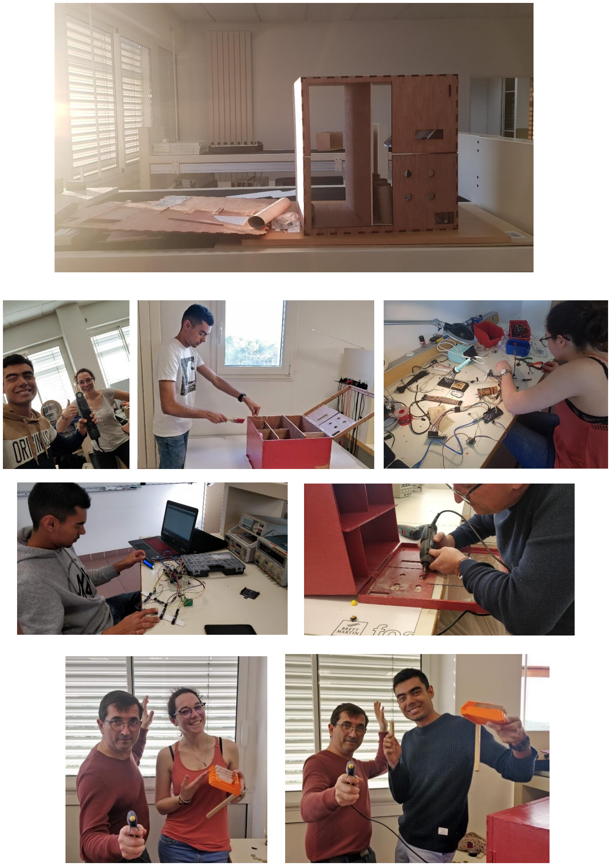
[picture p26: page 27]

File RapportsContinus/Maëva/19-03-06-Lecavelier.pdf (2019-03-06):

Rapport du 17/12/2018

Ce qu’on a fait vendredi 14/12 :


On est allés au FabLab pour couper nos planches pour faire la structure de la boîte. On a rencontré un problème avec une des planches : on voulait faire une planche de 400*400 mm mais la découpeuse laser n’accepte que les planches qui font entre 310*605mm… Donc on a essayé de modifier le fichier Inkscape, pour diviser la grande planche en 2 petites planches de 200*400, mais on a eu un problème avec les « dents » :

Celles de gauche sont trop petites, on ne peut pas utiliser cette planche du coup. Donc on doit trouver une autre solution : on va prendre le fichier qu’on avait déjà et le déplacer en dehors de la zone d’impression pour ne couper que la moitié de la planche 400*400. En le faisant deux fois et en assemblant les deux planches (avec une réglette en fer et des vis) normalement ça devrait marcher… Affaire à suivre mercredi 19/12.


Aujourd’hui :

13h30-15h :

On s‘est occupé de la partie du monnayeur surtout. On voulait faire toutes les petites pièces rapides qu’on avait à faire : les réglettes qui guident les pièces, les tubes qui récoltent les pièces et les vis sans fin.

Je me suis occupée de faire les vis sans fin, grâce à une bombe de peinture qu’Océane m’a prêté. J’ai enroulé du fil métallique autour de cette bombe, et voilà le résultat :


Ensuite on a visualisé comment on allait pouvoir tout installer dans la boîte. On est allé prendre des matériaux puis on a tout découpé pour que ça aille.

J’ai d’abord découpé la grande partie blanche qui va servir pour faire les réglettes, puis Clément a dessiné et coupé les « barrières » séparatrices. J’ai ensuite collé ces barrières à la grande partie blanche. Ce qui donne :

En même temps, on a coupé un long tube en carton en petit tube pour faire les collecteurs de pièce :


15h-16h30 :

Sur la deuxième partie du cours, j’ai agrafé les petits rouleaux collecteurs.


Ensuite, on a tout assemblé sur nos planches, et tester avec les détecteurs IR si tout fonctionnait bien :


Et nickel ! Il va falloir qu’on détermine la position finale des capteurs. Nous n’arrivons pas à nous mettre d’accord…

Sans oublier Olivia qui nous a bien aidés pendant ces phases de test et le reste de l’heure !

Rapport du 07/01/19

Durant les vacances, nous nous sommes vus avec Clément pour faire (presque) toutes les petites pièces pour assembler les grosses pièces. Nous sommes donc passés au fab lab, pour faire les trous dans les planches principales que nous avions, j’ai fait des ajustements sur la longueur du rail (blanc) : il était trop long pour passer dans l’espace prévu pour le système


Les appartements Thésa sont vite remplis…


Le système de tri de pièce mis en place : un problème demeure : où peut-on placer les capteurs IR ?


J’ai aussi fait les fichiers Inkscape pour les détails qu’on a rajoutés : la fente pour mettre les pièces, le trou pour l’écran, pour les boutons, pour le rendu de monnaie mais aussi pour les petites pièces qui vont faire la liaison entre le moteur et l’objet (encore plus ou moins indéterminé : bois, carton ?) qui sera fixé aux vis sans fin.

On a eu quelques problèmes : les trous pour les boutons sont trop grands (problème résolu : on va mettre du plastique ( ?) derrière pour pouvoir mettre des LEDS), et les pièces pour le moteur ont un trou trop grand, la tige qui tourne du moteur « nage » dans cet espace (non résolu)… Maintenant pour la séance d’aujourd’hui, on a assemblé les grandes parties de notre distributeur. En faisant cela, on s’est rendu compte qu’on avait oublié de prévoir la porte pour accéder à la fois au système et pour recharger la machine… Le problème n’a pas été résolu aujourd’hui. Cependant, on a fixé l’endroit où les capteurs IR iront : sur le dessus du rail, avec du scotch noir dessous qui absorbe les rayons IR et donc ceux-ci sont réfléchis uniquement lorsqu’une pièce passe devant. Pour ce faire, on a accroché les capteurs sur du PVC, qu’on fixera (de façon encore indéterminée) au-dessus du rail blanc.


En ayant fixé les bords extérieurs, on a pu installer provisoirement le système :

On peut voir les morceaux de scotch noir qui permettent le bon fonctionnement de la détection de pièces.

Et enfin, on a collé la planche de derrière (qui était en 2 morceaux car la planche entière ne passait pas dans la découpeuse laser) :

Notre distributeur à la fin de la journée ressemble à :

Rapport du 14/01/19

Durant la semaine j’ai fait la partie code sur le moteur.

Dans la première partie du cours on a fait la porte. De 13h30 à 14h on a d’abord regardé comment fonctionnait le code dans son intégralité. Il y a quelques problèmes dont on n’a pas su trouver la source mais qui seront je pense rapidement résolu. Puis nous avons commencé la porte. A l’aide de cet outil :


Nous avons découpé la face avant de notre distributeur, afin d’ensuite y visser des charnières et un aimant pour maintenir la porte fermée :


Ensuite, nous avons finalisé quelques petites choses : on a fixé la cloison du milieu et celle qui supportera le système. A la fin de la journée, notre projet ressemblait à ça :


Rapport du 06/02/19

Depuis la dernière fois, on a peint notre projet, on a fixé une vitre en plexiglass, on a trouvé un moyen de guider les pièces de la fente vers la pièce qui trie les pièces. M. Masson nous a également fait des trous pour qu’on puisse passer les boutons au travers de la façade avant.

En voulant vérifier que tout le système passait dans l’espace dédié à cela, on a vu que les plaques de test en plastique étaient trop grosses, du coup j’ai soudé les câbles à une petite plaque beaucoup plus pratique. Clément a découpé des pièces en bois qui permettront de maintenir la vis sans fin contre le moteur.

Les pièces
en bois que
Clément a
faites.

Les trous

pour les boutons
(avec les boutons
dedans déjà)

L’écran dans la fente
faite pour.


Le bazar de câbles


Notre projet à la fin de la séance.

Rapport du 13/02/19

Vendredi 08/02/19

J’ai rangé les câbles (en les scotchant entre eux) de notre système pour y voir plus clair, on a fixé tous nos éléments (la pièce 3D qui trie, le rail en PVC et les rouleaux qui stockent les pièces). Puis sur ces derniers on a fixé les capteurs IR, on a accroché les boutons. On a également mis l’écran dans la fente dédié à cet effet.

J’ai dû refaire les mêmes pièces en bois que Clément a fait pour que le système d’accroche fonctionne.

Ensuite, nous sommes allés au FabLab pour découper quelques pièces d’acrylique pour combler les erreurs (trous trop gros au-dessus des boutons, fente assez large au milieu de la face avant. Pendant ce temps, Clément a pris en main la guirlande de LED qu’on a eu pour faire joli.

Ensuite on est passés aux phases de test. On a dû vérifier que tout était bien branché, que les pièces assemblées entre elles faisaient bien fonctionner le système. On a eu quelques petits problèmes, mais en soit le distributeur était fonctionnel. Seul bémol, les moteurs tournaient à l’envers, donc Clément a corrigé ça le soir même.

Samedi 09/02/19 :

On a été au Play Azur Festival où les gens ont apprécié notre projet. On a eu quelques galères : pièces qui passaient mal dans le rail, donc le détecteur IR ne les détectait pas, les moteurs qui ne tournaient plus au bout d’un moment, les pièces en bois qui se décrochaient des moteurs pas-à-pas, le produit qui ne tombaient pas, etc… Les solutions : réimprimer une grande pièce en 3D qui rassemble tous les éléments qu’on a fait un peu en système D, reset de temps en temps la carte pour un meilleur fonctionnement des moteurs, changer la matière de nos vis sans fin et enfin utiliser des moyeux pour bien maintenir les vis sans fin dans les moteurs.

Mercredi 13/02/19 :

Aujourd’hui je n’ai pas fait beaucoup de chose. Pour rendre le projet plus propre et éviter d’avoir des problèmes dus aux imperfections de l’agencement des pièces à l’intérieur (tenu par du scotch, ou encore les pièces de monnaie qui tombent sur la carte Arduino…), on a décidé de refaire toutes nos pièces en 3D. Pour l’instant ça ressemble à ça :

Il y a les rails (qui sont pour l’instant en PVC), les tubes (qui sont pour l’instant un gros rouleau de carton découpé et pas droits), un toboggan qui ramènera les pièces dans un endroit facilement accessible. Ensuite, dans la partie haute (au-dessus des rails) viendra se fixer la pièce qui permet de trier les pièces de monnaies. Puis, la petite pièce en PVC tordue sera aussi modélisée et enfin la pièce en polystyrène qui permet de faire le bon angle du monnayeur. Puis, il y aura des emplacements pour qu’on puisse fixer les capteurs IR et pour que les câbles ne gênent pas les pièces de monnaies qui glissent. Il y aura aussi certainement des emplacements pour pouvoir glisser les cartes Arduino dedans, pour que les câbles soient bien rangés et le montage clair. J’espère la finir rapidement pour vite l’imprimer et donner plus de beauté intérieure à notre projet.


Rapport du 27/02/2019

Aujourd’hui, on a fait quelques modifications pour rendre notre projet plus solide et plus beau. Clément s’est occupé d’installer des LED derrière les plaques de plexiglass des boutons, comme ça, lorsqu’on appuie sur un bouton, la LED s’allume et on voit sur quel bouton on a appuyé. De plus, il a aussi fait en sorte qu’elle reste allumée le temps que le produit distribué tombe.

Pour ma part, j’ai refait les vis sans fin en aluminium. Pour cela, j’ai enroulé une tige d’environ 60 cm autour d’un tube en PVC afin de former une sorte de gros ressort. Puis, j’ai fixé les pièces en bois qui étaient sur les anciennes vis pour pouvoir l’accrocher au moteur. Je n’ai pas pu m’occuper des moyeux encore.

Ensuite, j’ai continué le modèle 3D depuis la dernière fois. Je l’ai allégé au niveau du bas de la pièce pour raccourcir le temps d’impression (estimé initialement à, environ, 24h) cela donne :

Donc, on a toujours le même rail pour faire glisser les pièces. J’ai rajouté un « bande » au milieu vers le bas sur laquelle on pourra fixer les capteur IR. Puis, j’ai (enfin) réussi à créer un rail penché dans lequel on va pouvoir mettre le trieur de pièces. Il manque encore les trous dans lesquels vont passer les pieds (je le fais en plusieurs parties pour faciliter l’impression, avoir une meilleure précision (précision faible sur l’axe z) et pour diminuer les temps d’impression). Ensuite, il manquera les tubes récepteurs qui amèneront les pièces vers un rail pour qu’elles glissent jusqu’à un tube prévu à cet effet (comme il y avait dans la version précédente).

Mais déjà, pour la JPO du 02/03 je voudrais finir cette pièce pour l’imprimer et que ça fasse propre dans le distributeur. Voilà la pièce imprimée :


Rapport du 06/03/2019

Aujourd’hui nous avons pu finir les optimisations et finir notre projet. Pour cela, Clément s’est occupé de la partie Bluetooth. Pour ma part, j’ai limé les trous que nous avions percé dans la pièce orange pour laisser la place au capteur IR, j’ai percé également de petits trous pour visser ces mêmes capteurs.

Enfin, j’ai limé l’endroit où aller glisser le trieur de pièce pour que ce soit bien propre. On s’était rendu compte que la trieuse était capricieuse en fonction de l’angle, et du rail supérieur qui servait à la maintenir. Donc j’ai enlevé ce rail.

Ensuite, j’ai fait des tests et je me suis aperçu que certaines pièces allaient trop loin et sortaient de leur rail. J’ai donc collé au pistolet à colle des morceaux de bois cartonné pour bloquer l’accès aux pièces.


Après, j’ai coupé des tasseaux de bois pour faire les pieds. Clément m’a aidé à prendre les mesures. Il a néanmoins fallu faire quelques réajustements (coupé un peu parce que certains pieds étaient trop longs, coupé le haut en biais pour bien épouser la forme de la pièce qui allait être penchée, etc…)


Puis, il a fallu faire un rail pour lier la fente à notre pièce. C’était très difficilement réalisable, j’ai donc fait une autre fente au niveau du début de la trieuse de pièce. Après quelques essais de rails, nous nous sommes rendu compte avec M. Masson que la pièce était trop haute, la pente était trop faible pour que la pièce glisse dans le rail en PVC. Donc M. Masson a coupé les pieds, puis s’est occupé de fixer le rail en PVC.

Finalement, à la fin de cette journée, notre projet fonctionne (pour l’instant) parfaitement, on peut payer grâce au téléphone portable et en plus il s’allume et éclaire dans le noir !


2 photos pour monter l’intérieur du projet, et comment tout est installé.


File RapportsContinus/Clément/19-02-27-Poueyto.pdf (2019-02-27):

POUEYTO Clement

Binome : Lecavelier Maeva

Rapport de séance du 27/02/2019

Lors de cette séance nous avons moins avancé par rapport aux dernières séances car le projet est déjà fonctionnel, il ne reste que quelques ajustements à réaliser.

J’ai consacré la majeure partie de la séance à m’occuper des LED rgb qui se situent au-dessus des boutons. Pour cela j’ai découpé 4 LED d’une bande de LED rgb qui ont été soudé entre-elles avec l’aide de Mr. Masson.

J’ai collé les lumières au pistolet à colle et relié la nouvelle bande à la carte arduino.


Une des difficultés a été de se replonger dans le fonctionnement des LED en utilisant la bibliothèque « adafruit ».

Dans la partie programmation, j’ai créé de nouvelles fonctions pour changer la couleur des lumières en fonction des actions de l’utilisateur.

Rouge : lorsqu’il manque de l’argent, Vert : lorsque l’achat est validé, Bleu sinon.

Pendant ce temps Maeva a reformé les vis infinis en aluminium car le matériau est plus solide, elle a ensuite repris la conception des pièces sur logiciel pour les imprimer en 3D.


Il ne manque plus que la partie bluetooth à réaliser pour valider le cahier des charges du projet.

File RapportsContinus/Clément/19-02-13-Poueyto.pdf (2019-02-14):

Poueyto Clement

Binôme : Lecavelier Maeva

Rapport de séance du 13/02/2019

Le projet beaucoup avancé depuis la dernière séance car il devait être présentable pour le playAzurFestival. Nous avons passé la journée du vendredi 08/02 a travaillé dessus.


Maeva s’est occupée de ranger le système de l’arduino en rassemblant les fils et en soudant les différents éléments pour gagner de la place en se séparant des plaques de testes.

Pour ma part, j’ai découpé les pièces en bois qui relient la vis infinie au moteur et j’ai vissé les moteurs au fond du distributeur.


Il a fallu redécouper d’autres pièces en bois pour coincer le bout de la vis infini entre 2 plaques de bois.

Nous nous sommes rendus au FabLab pour découper des pièces d’acrylique.

J’ai pris en main la bande de LED avec la bibliothèque « adafruit » qui facilite son utilisation.

Nous l’avons collé sur la face avant pour décorer le distributeur.

J’ai finis la partie code du projet en implémentant l’utilisation de la bande de LED et des LED RGB des boutons. Désormais la bande clignote de différentes couleurs ( code pris sur internet) et imite une barre de chargement lorsqu’un achat est réalisé.


Durant cette séance nous avons avancé plus lentement car ne il reste plus que quelques détails à régler.

Maeva a commencé à modéliser les pièces coté système en 3D sur autodesk afin de les imprimer en 3D, pour que le trajet des pièces de monnaies soit moins aléatoire et plus propre.

J’ai soudé des fils intermédiaires au bouton pour que les câbles soient plus longs car il était impossible d’ouvrir la porte avant du distributeur. J’ai collé au pistolet à colle les boutons pour pouvoir effectuer une pression dessus.

Il faut encore souder les LED rgb aux résistances et les reliées au système arduino, ainsi que changer 2 des 4 moteurs qui ont une puissance trop faible pour tourner lorsque la vis infinie est accrochée.

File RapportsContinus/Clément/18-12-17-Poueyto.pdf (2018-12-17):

Poueyto Clément G2

Compte rendu de séance du 17/12/2018

Objectifs de la séance

- Terminer l’assemblage du monnayeur (aspect physique)
- Faire le code du bouton
- Créer les différentes pièces du monnayeur

Avant la séance nous étions allés au FabLab afin de découpé la structure en bois de notre distributeur. Nous avions 4 planches de 400x800 mm que nous avons découpé a la scie sauteuse en planches de 400x300 mm afin de convenir aux dimensions de la machine pour la découpe au laser.


Nous avions préalablement installé Inkscape et créé le fichier de découpe de notre boîte en utilisant l'extension lasercut qui nous a aidé à modéliser une boîte qui s'assemble comme un puzzle.

Nous avons obtenu 4 faces de 400x300 mm, cependant les 2 faces manquantes de 400x400 mm n'etaient pas faisable en une fois dans la machine. Nous avons donc découpé le fichier en 2 parties mais nous avons rencontré un problème d'impression. Nous retournons donc au FabLab le mercredi 19/12 afin de résoudre ce problème.


De 13h30 à 15h00

Pendant la première partie nous avons entamé la conception des différentes parties du monnayeur : les tubes pour stocker les pièces, la reglette qui amène les pièces dans les tubes et la vis infini qui sera rattachée au moteur. Nous avons réfléchi à la manière dont nous allions disposer les différentes pièces afin de rendre le système le plus compacte et efficace possible.

Nous avons pris un long tube en carton que nous avons découpé en 5 parties pour les 5 pièces différentes (2€,1€,50c,20c,10c). La contrainte était d’utiliser un cylindre qui pouvait contenir les 5 différentes tailles de pièces tout en les faisant s’empiler une fois à l’intérieur du cylindre.


Nous avons testé différentes tailles de vis sans fin et nous avons étudié le procédé afin d’optimiser l’avancement du produit dans la vis. Nous en avons conclu qu'il fallait que la vis ne touche pas la surface autour d'elle.


Puis nous avons commencé à créer la réglette en PVC ainsi que les rails qui guideront la pièce dans les tubes, nous les avons découpé et collé.


De 15h00 à 16h30

Ensuite nous avons collé les 5 tubes ensemble avec des agrafes de manière à compacter le collecteur de pièces.

J'ai réalisé le code du bouton , afin de prendre en compte les achats du client. J’ai créé une fonction qui réceptionne le choix du client et une fonction qui affiche sur l’écran le résultat de la commande.

La plus grande difficulté de cette séance a été de faire la reglette car cela a pris du temps à récupérer les mesures. Les différents tests du fonctionnement du monnayeur ont pris aussi beaucoup de temps.

En effet il a fallu tester le comportement de la pièce dans le système du monnayeur selon l’inclinaison, la vitesse et sa disposition. On en a conclut que la partie qui trie les pièces doit être inclinée de 15° autour de l'axe X et 55° autour de l'axe Y.


Nous n'avons pas pu assembler toutes les pièces car nous pensions qu'il était plus cohérent de finir la conception de toutes les pièces avant de finir l'assemblage final.

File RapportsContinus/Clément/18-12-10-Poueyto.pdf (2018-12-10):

Poueyto Clément G2 – binome : Maëva Lecavalier

Rapport de séance du 10/12/2018

Projet arduino : distributeur de nourriture.

Objectif de la séance sur 3h :

- Faire le montage arduino du système
- Réaliser le code arduino pour le détecteur IR et l’écran LCD
- Mettre en place le Github
- Créer un compte gmail et YouTube en commun
- Mettre en place le planning et le cahier des charges
- Tracer sur le logiciel inkscape le schéma de la boîte du distributeur pour la découpe laser

Avant de venir à cette première séance dédiée au projet, nous avions le plan de notre distributeur sur Autodesk et Maëva avait imprimé en 3D le monnayeur .

Rapport de la séance 1 : 13h30-15h00

Après la présentation du déroulement du projet je me suis occupé du montage du système électronique d'arduino ( branchement de l’écran lcd ainsi que des capteurs IR).

Avec Maëva, nous avons étudié le principe du capteur infrarouge et nous avons réglé sa sensibilité afin qu'il ne détecte pas la surface du distributeur mais seulement celle de la pièce. Nous avons également testé un autre dispositif de capteur IR (infrarouge) , cependant il ne s’adaptait pas à la structure de notre montage.

J'ai également commencé le code arduino du système.


Pendant ce temps, Maëva s'est occupée de mettre en place le site de Github, de créer le planning et le cahier des charges.

Rapport de la séance 2 : 15h00-16h30

La deuxième partie est principalement centrée sur la partie code. En effet, j'ai réalisé le code pour faire fonctionner le système en le partitionnant en plusieurs fonctions. Premièrement une fonction afin de faire fonctionner l’écran et lui faire afficher le menu d'accueil du distributeur ainsi que les crédits qui sont insérés.


J'ai appris à utiliser le code des capteurs IR afin qu'ils réagissent lorsqu’une pièce passe dans le périmètre de détection . Lorsqu'une pièce est insérée une variable « crédit » est incrémenté. Puis elle est remise à zéro si aucune autre pièce n'est détectée au bout de 30 secondes (modifiable à l'avenir).

Enfin nous avons installé le logiciel Inkscape et commencé le schéma de découpe des planches de notre distributeur.

Finalement nos objectifs sont presque remplis.

Durant ces 3 heures la principale difficulté que nous avons rencontré est le réglage de la précision du capteur IR qui peut être réglé en utilisant le potentiomètre sur le module.


En effet le capteur détectait un objet à une trop grande distance comme le mur de notre distributeur, il était donc constamment activé.

Le code est fonctionnel, cependant l’objectif de la prochaine séance sera de l’améliorer en y implémentant de nouvelles fonctions, et de commencer l'assemblage des planches du distributeur.

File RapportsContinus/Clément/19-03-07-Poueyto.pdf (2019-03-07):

Poueyto Clément G2

Binome : Lecavlier Maeva

Rapport de séance du 06/03/2019

Pour cette dernière séance notre but était de finir le projet.

Maëva a imprimé en 3D le nouveau monnayeur qu’elle a modélisé durant les séances précédentes.

Nous avons donc retiré l’ancien rail qui faisait glisser les pièces par celui-ci qui est plus solide.

Maëva a coupé des bouts de bois pour réaliser les pieds du monnayeur.

Nous avons percé et vissé les capteurs IR à la nouvelle pièce et collé des bouts de bois pour empêcher les pièces de monnaies de tomber dans les mauvais compartiments.


Pendant ce temps je me suis occupé de rajouter la partie bluetooth au système.

J’ai réalisé le code pour pouvoir « payer » via l’application « bluetooth electronic », on peut donc rajouter du crédit directement via le téléphone. J’ai donc modifié le code afin d’implémenter cette partie.


Cependant la fente dans laquelle on introduisait les pièces de monnaies ne correspondait plus avec celle du trieur.

Nous avons testé différentes solutions pour résoudre ce problème comme couper les pieds du monnayeur. Mr Masson nous a aidé à résoudre le problème.

Finalement nous avons découpé dans la face avant du distributeur une nouvelle fente et recouvert l’ancienne avec un bout de bois.

Le projet est donc fini et fonctionne très bien.

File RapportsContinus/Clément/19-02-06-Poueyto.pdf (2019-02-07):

Poueyto

Clément

06/02/2019

Binôme : Maeva Lecavelier

Rapport de séance du 06/02/2019

Depuis la dernière séance nous avons peint les faces intérieures et extérieures du distributeur en rouge (2 couches de peinture). Nous avons aussi fixé les autres cloisons séparant les moteurs.


Nous avons découpé du plexiglass qui sert de vitre au distributeur de manière à pouvoir récupérer les produits achetés. Nous avons percé et vissé la plaque pour la fixer à la porte.


Avec l’aide de Mr. Masson, nous avons taillé de nouveaux trous pour les boutons car les anciens étaient trop grands. Ils serviront donc de décoration afin d’éclairer le bouton qui aura été pressé.

Nous avons remplacé l’ancienne carte Arduino Uno par une carte Arduino Mega car elle possède beaucoup plus de sorties. Elle était donc indispensable afin de brancher tous les moteurs sur une seule carte.

Nous avons étudié le programme des moteurs et nous l’avons incorporé au fichier « main ».

Le moteur tourne correctement cependant nous ne savons pas encore comment l’arrêter.

Aujourd’hui, je me suis occupé de créer les 4 pièces en bois reliant l’embout du moteur à la vis infini.

Il a fallu découper à la scie les quatre pièces et percé au centre pour coincer le moteur à l’intérieur tout en limant pour ajuster les dimensions. Pendant ce temps Maëva s’est occupée de modeler une pièce reliée au monnayeur et à la fente pour insérer la monnaie car l’ancienne était défectueuse.


Par la suite nous avons dus réaliser plusieurs tests pour scotcher (double face) le monnayeur et le toboggan à l’intérieur de la structure. Une fois fixé nous avons rentré le système électronique à l’intérieur du distributeur. Il a fallu découper et ajuter certaines pièces qui étaient trop grandes pour rentrer.

Avec Maëva nous avons souder les 4 boutons de la face avant avec des fils reliés au système.

Dans l’ensemble le système est fonctionnel mais il manque encore quelques détails pour finaliser le projet.


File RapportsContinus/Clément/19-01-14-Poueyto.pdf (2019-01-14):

POUEYTO
CLEMENT

Binôme : Maeva Lecavelier

Rapport de séance du 14/01/2019

Au début de cette séance nous avons étudié le fonctionnement du code du moteur pas à pas et nous avons rajouté la partie code du moteur, cependant nous n’avons pas assez de pin sur la carte arduino pour connecter les 4 moteurs. Il faudra donc lier les 2 cartes arduino en maitre/esclave dans les prochaines séances car elles doivent forcément communiquer entre elles.


Lors de la dernière séance nous avions collé la structure du distributeur mais nous avions oublié de prendre en compte l’ouverture de celui-ci. Nous avons donc réglé ce problème avec l’aide de notre professeur Mr. Masson.


Il a fallu découpé la face avant du distributeur qui sert désormais de porte.


Pour faire tenir la porte nous avons utilisé des charnières que nous avons fixé en utilisant des vis.

Une fois la porte fixé nous avons vissé un aimant ainsi qu’une équerre métalique qui permettra de la retenir.

Pour finir, après l’oral nous avons commencé a collé les planches à l’interieur du distributeur afin de pouvoir peindre celui-ci lors de la prochaine séance.

Nous avons donc collé avec de la colle à bois la cloison séparant le système electronique de la partie visible ainsi que la planche sur laquelle reposera le système ainsi que la récuperation des pièces.


L’objectif de la prochaine séance sera de fixé les planches de la partie visible du distributeur afin de pouvoir peindre l’intérieur et l’exterieur en rouge.

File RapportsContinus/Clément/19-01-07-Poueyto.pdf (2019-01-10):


POUEYTO
Clément

Binôme : Maëva Lecavelier

Rapport de séance du 07/12/2019

Rapport des vacances :

J’ai ajouté des fichiers de « debuggage » pour chaque composant (IR, écran, potentiomètre, bouton) du système afin de vérifier si chacun d’eux fonctionnent correctement et j’ai aussi modifier le code en le commentant pour qu’il soit plus lisible. Le code du bouton (software) a été fait.

J’ai créé une représentation en 3D du distributeur sur le logiciel Autodesk pour savoir vers quelle direction nous nous dirigeons, et voir quelles pièces étaient manquantes au bon fonctionnement du système.

Avec Maëva, nous avons coupé la pièce sur laquelle la monnaie glisse dans le tube afin de rendre le système plus compact.


J’ai sculpté dans du polystyrène l’élément permettant d’incliner le monnayeur de 55° et je les ai collé. Pendant ce temps Maëva a dessiné la face avant du distributeur sur Inkscape. Puis nous nous
sommes rendu au FabLab pour utiliser la découpeuse laser et nous avons découpé les planches sur lequel les moteurs reposeront et fais les cloisons qui séparent les parties du distributeurs ainsi que le toboggan qui fera glisser la monnaie rendue.

Rapport de séance

L’objectif de cette séance est d’assemblé les différentes pièces que nous avons conçu pendant les vacances. Ainsi nous avons fixé 5 surfaces du distributeur avec de la colle adaptée pour le bois. La difficulté a été de stabiliser la construction le temps que la colle soit efficace.


Nous avons placé des équerres temporaires pour consolider et fixer les planches.

Pendant que Maëva s’occuper de fixer les detecteurs infrarouges, j’ai découpé les planches de bois pour faire la cloison du milieu qui sépare le système electronique de la partie visible.

Nous avons choisi de fixer les detecteurs en haut de la glissière et nous avons mis du scotch noir sous les capteurs pour ne pas qu’ils soient activés en permanence car le noir ne renvoie pas l’infrarouge.


Nous avons placé les différentes parties du systèmes à l’interieur du distributeur et réalisé des essais plus concret de la trajectoire de la pièce insérée pour s’adapter aux contraintes des dimensions.

L’objectif de la prochaine séance sera de continuer l’assemblage des autres parties.

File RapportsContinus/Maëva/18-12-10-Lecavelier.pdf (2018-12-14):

Rapport du 10 décembre 2018

De 13h30 à 15h.

Ce que j’ai fait avant :

- Phase de recherche pour savoir ce qui a déjà été fait et comment on peut faire.
- Représenter et imprimer la pièce monnayeur qui trie les pièces.
- Représenter le projet en 3D pour voir comment vont s’organiser les différents éléments
- Télécharger les différentes logiciels utiles (Auto Desk Inventor, Inkscape…)

Pendant que Clément finissait de faire le monnayeur, en gérant le système de comptage de pièce, je me suis occupée de faire les GitHub et de tout mettre en ligne dessus : représentation 3D du projet, objectif final, présentation rapide de ce qu’on veut faire. J’ai aussi aidé Clément à calibrer les capteur IR. Ce calibrage est important pour savoir comment on va les installer dans la boîte, et pour qu’ils se déclenchent uniquement quand une pièce passe devant (et non pas que le mur du distributeur soit capté).

De 15h à 16h30.

On s’est fixé sur comment utiliser les capteurs IR : on va les mettre dans les petites réglettes qui vont guider les pièces, et la pièce va passer sur le détecteur, le déclenchant à tous les coups. Ensuite, j’ai commencé à prendre en main le logiciel Inkscape.


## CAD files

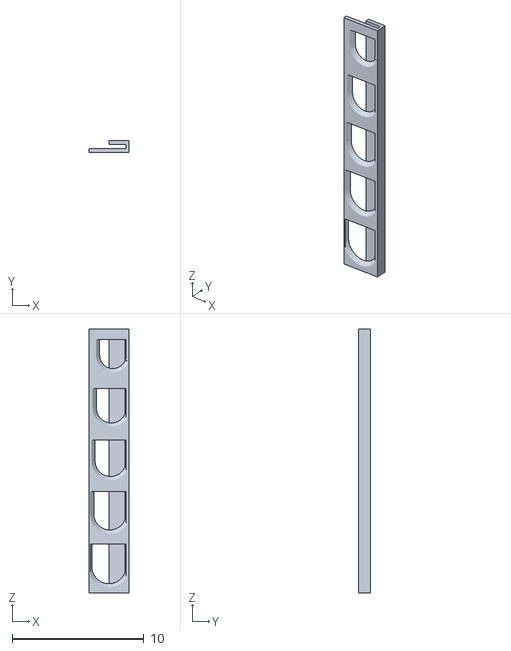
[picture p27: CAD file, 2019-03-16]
ConstructionProjet/Réprésentation3D/Monnayeur/V1.stl
3.00 x 0.9 x 20.0

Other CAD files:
ConstructionProjet/Réprésentation3D/Clément/Pièce-interieur-3.ipt
ConstructionProjet/Réprésentation3D/Clément/Pièce-moteur-vis.ipt
ConstructionProjet/Réprésentation3D/Clément/Pièce-moteur-vis_CPY.ipt
ConstructionProjet/Réprésentation3D/Clément/Pièce-moteur-vis_CPY1.ipt
ConstructionProjet/Réprésentation3D/Clément/Pièce-moteur-vis_CPY2.ipt
ConstructionProjet/Réprésentation3D/Clément/cale-moteur.ipt
ConstructionProjet/Réprésentation3D/Clément/cale_monnayeur.ipt
ConstructionProjet/Réprésentation3D/Clément/cloison_porte-monnayeur.ipt
ConstructionProjet/Réprésentation3D/Clément/distributeur.iam
ConstructionProjet/Réprésentation3D/Clément/face-avant.ipt
ConstructionProjet/Réprésentation3D/Clément/monnayeur.ipt
ConstructionProjet/Réprésentation3D/Clément/piece-interieur-2.ipt
ConstructionProjet/Réprésentation3D/Clément/piece-interieur4.ipt
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

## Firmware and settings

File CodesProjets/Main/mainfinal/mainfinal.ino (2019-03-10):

#include <LiquidCrystal.h>
#include <Stepper.h>
#include <Adafruit_NeoPixel.h>

#define IN1 22
#define IN2 23
#define IN3 24
#define IN4 25 // moteur1

#define IN5 26
#define IN6 27
#define IN7 28
#define IN8 29//moteur2

#define IN9 30
#define IN10 31
#define IN11 32
#define IN12 33//moteur3

#define IN13 34
#define IN14 35
#define IN15 36
#define IN16 37//moteur4

char Data;
int temp =5;
int m=0;
int nombreDePas=32*64;
LiquidCrystal lcd(2,3,4,5,6,7); //écran
Adafruit_NeoPixel strip = Adafruit_NeoPixel(22, 20, NEO_GRB + NEO_KHZ800);
Adafruit_NeoPixel stripBouton = Adafruit_NeoPixel(4, 52, NEO_GRB + NEO_KHZ800);

const int bouton1=10;
const int bouton2=9;
const int bouton3=8;
const int bouton4=11;

int validation=0;
int var1;
int i=1;
double prix=1;
double credit=0;
double newcred=-1;
unsigned long Temps;
long intervalle;
long chrono;
int val1;
int val2;
int val3;
int val4;



void setupEcran(){ //initialise l'écran de bienvenue
  lcd.clear();
  lcd.setCursor(0,0);
  lcd.print("Bienvenue au");
  lcd.setCursor(0,1);
  lcd.print("PolyShop");
  }


void temps(){
  intervalle=millis()-chrono;//intervalle = temps actuel - temps du chrono
  if (credit>0&&intervalle>30000){//s'il y a des crédits et au bout d'un certain intervalle de temps
      credit=0;
      setupEcran();
      }
  }

void bluetooth(){
  if (Serial1.available()){Data=Serial1.read();
  Serial.print(Data);
    switch(Data){
      case 'A':
      credit=credit+2;
      break;
      case 'B':
      credit=credit+0.5;
      break;
      case 'C':
      credit=credit+1;
      break;
      case 'D':
      credit=credit+0.2;
      break;
      case 'E':
      credit=credit+0.1;
      break;
      case 'F':
      credit=0;
      setupEcran();
      break;
      }
    }
  }

void checkPiece(){ //verifie si une piece est insérée dans la machine
    for (int i=0; i<5; i++){ //parcours detecteur IR 1 à 5
      var1=analogRead(i);     
        if (var1<400){
          if (i==0){
            credit=credit+2;}
          else if(i==1){
            credit=credit+0.5;}
          else if(i==2){
            credit=credit+1;}
          else if(i==3){
            credit=credit+0.2;}
          else {
            credit=credit+0.1;}
  
          Serial.print(credit);
          Serial.println(" euros");
          chrono=millis();//lance le chrono (ref fonction "temps")
          delay(1000);
          }
       }
  }

void afficheCredit(){ //affiche le nombre de crédit actuellement
  if(credit!=newcred&&credit>0){
    lcd.clear();
    lcd.setCursor(0,0);
    lcd.print("Credits : ");
    lcd.print(credit);}
  }

void checkBouton(){//vérifie si un bouton a été préssé
   val1=digitalRead(bouton1);
   val2=digitalRead(bouton2);
   val3=digitalRead(bouton3);
   val4=digitalRead(bouton4);
  }

void ecranErreur(){//affiche le nombre de crédits manquant
  lcd.clear();
  lcd.setCursor(0,0);
  lcd.print("Il manque ");
  lcd.setCursor(0,1);
  lcd.print(prix-credit);
  lcd.print(" euro(s)");  
}

void ecranAchat(){//affiche le message de confirmation d'achat.
  lcd.clear();
  lcd.setCursor(0,0);
  lcd.print("Merci pour");
  lcd.setCursor(0,1);
  lcd.print("votre achat");}

void erreurAchat(){//traite le cas dans lequel il manque des crédits pour un achat.
  checkBouton();
  if(credit<prix){
    if(val1==LOW||val2==LOW||val3==LOW||val4==LOW){
      if(val1==LOW){stripBouton.setPixelColor(2, 223, 0, 0);
    stripBouton.show();}
      if(val2==LOW){stripBouton.setPixelColor(3, 223, 0, 0);
    stripBouton.show();}
      if(val3==LOW){stripBouton.setPixelColor(1, 223, 0, 0);
    stripBouton.show();}
      if(val4==LOW){stripBouton.setPixelColor(0, 223, 0, 0);
    stripBouton.show();}
      lumiere(223,0,0);
      ecranErreur();
      }
    }
  }

 void chargement(int n){
  if(n%23==0){  
    strip.setPixelColor(n/23,0,223,0);
    strip.show();}
  }

void moteur1(){Serial.begin(115200);
pinMode(IN1, OUTPUT);
pinMode(IN2, OUTPUT);
pinMode(IN3, OUTPUT);
pinMode(IN4, OUTPUT);
for (m=0; m <= 511; m++){
Serial.println(m);
chargement(m);
digitalWrite(IN4, HIGH);
digitalWrite(IN3, LOW);
digitalWrite(IN2, LOW);
digitalWrite(IN1, LOW);
delay(temp);
digitalWrite(IN4, LOW);
digitalWrite(IN3, HIGH);
digitalWrite(IN2, LOW);
digitalWrite(IN1, LOW);
delay(temp);
digitalWrite(IN4, LOW);
digitalWrite(IN3, LOW);
digitalWrite(IN2, HIGH);
digitalWrite(IN1, LOW);
delay(temp);
digitalWrite(IN4, LOW);
digitalWrite(IN3, LOW);
digitalWrite(IN2, LOW);
digitalWrite(IN1, HIGH);
delay(temp); }}

void moteur2(){Serial.begin(115200);
pinMode(IN5, OUTPUT);
pinMode(IN6, OUTPUT);
pinMode(IN7, OUTPUT);
pinMode(IN8, OUTPUT);
for (m=0; m <= 511; m++){
Serial.println(m);
chargement(m);
digitalWrite(IN8, HIGH);
digitalWrite(IN7, LOW);
digitalWrite(IN6, LOW);
digitalWrite(IN5, LOW);
delay(temp);
digitalWrite(IN8, LOW);
digitalWrite(IN7, HIGH);
digitalWrite(IN6, LOW);
digitalWrite(IN5, LOW);
delay(temp);
digitalWrite(IN8, LOW);
digitalWrite(IN7, LOW);
digitalWrite(IN6, HIGH);
digitalWrite(IN5, LOW);
delay(temp);
digitalWrite(IN8, LOW);
digitalWrite(IN7, LOW);
digitalWrite(IN6, LOW);
digitalWrite(IN5, HIGH);
delay(temp); }}

void moteur3(){Serial.begin(115200);
pinMode(IN9, OUTPUT);
pinMode(IN10, OUTPUT);
pinMode(IN11, OUTPUT);
pinMode(IN12, OUTPUT);
for (m=0; m <= 511; m++){
Serial.println(m);
chargement(m);
digitalWrite(IN12, HIGH);
digitalWrite(IN11, LOW);
digitalWrite(IN10, LOW);
digitalWrite(IN9, LOW);
delay(temp);
digitalWrite(IN12, LOW);
digitalWrite(IN11, HIGH);
digitalWrite(IN10, LOW);
digitalWrite(IN9, LOW);
delay(temp);
digitalWrite(IN12, LOW);
digitalWrite(IN11, LOW);
digitalWrite(IN10, HIGH);
digitalWrite(IN9, LOW);
delay(temp);
digitalWrite(IN12, LOW);
digitalWrite(IN11, LOW);
digitalWrite(IN10, LOW);
digitalWrite(IN9, HIGH);
delay(temp); }}

void moteur4(){Serial.begin(9600);
pinMode(IN16, OUTPUT);
pinMode(IN15, OUTPUT);
pinMode(IN14, OUTPUT);
pinMode(IN13, OUTPUT);
for (m=0; m <= 511; m++){
Serial.println(m);
chargement(m);
digitalWrite(IN16, HIGH);
digitalWrite(IN15, LOW);
digitalWrite(IN14, LOW);
digitalWrite(IN13, LOW);
delay(temp);
digitalWrite(IN16, LOW);
digitalWrite(IN15, HIGH);
digitalWrite(IN13, LOW);
digitalWrite(IN12, LOW);
delay(temp);
digitalWrite(IN16, LOW);
digitalWrite(IN15, LOW);
digitalWrite(IN14, HIGH);
digitalWrite(IN13, LOW);
delay(temp);
digitalWrite(IN16, LOW);
digitalWrite(IN15, LOW);
digitalWrite(IN13, LOW);
digitalWrite(IN12, HIGH);
delay(temp); }}

void achat(){
  if (credit>=prix){
    lumiere(223,0,0);
    checkBouton();
    if (val1==LOW){validation=1;
stripBouton.setPixelColor(2, 0, 223, 0);
    stripBouton.show();
    moteur1();}
    else if(val2==LOW){validation=2;
stripBouton.setPixelColor(3, 0, 223, 0);
    stripBouton.show(); 
    moteur2();}
    else if(val3==LOW){validation=3;
      stripBouton.setPixelColor(1, 0, 223, 0);
    stripBouton.show();
      moteur3();}
    else if(val4==LOW){validation=4;
    stripBouton.setPixelColor(0, 0, 223, 0);
    stripBouton.show();

      moteur4();}
    else {validation=0;}
      
      if (validation!=0){credit=credit-prix;
        ecranAchat();
        delay(1000);
        setupEcran(); }
  }
}

void resetLumiereBouton(){
     stripBouton.setPixelColor(0, 0, 0, 223);
     stripBouton.setPixelColor(1, 0, 0, 223);
     stripBouton.setPixelColor(2, 0, 0, 223);
     stripBouton.setPixelColor(3, 0, 0, 223);
     stripBouton.show();

}


void lumiere(int r,int g,int b){
  int X=22;
  for(int i = 0; i < X; i++ ) { // On fait une boucle pour définir la couleur de chaque led
        // setPixelColor(n° de led, Rouge, Vert, Bleu)
    strip.setPixelColor(i, 223, 0, 0);       
    }
    strip.show(); // on affiche 
  }

void setup() {
  pinMode(bouton1, INPUT);
  pinMode(bouton2, INPUT);
  pinMode(bouton3, INPUT);
  pinMode(bouton4, INPUT);
  lcd.begin(16,2);
  setupEcran();
  strip.begin();
  stripBouton.begin();
  lumiere(223,0,0);
  strip.show();
  Serial.begin(9600);
  Serial.println("Bonjour -Pret pour les commandes AT");
  Serial1.begin(9600);


}


void showStrip() {
 #ifdef ADAFRUIT_NEOPIXEL_H 
   // NeoPixel
   strip.show();
 #endif
 #ifndef ADAFRUIT_NEOPIXEL_H
   // FastLED
   FastLED.show();
 #endif
}

void setPixel(int Pixel, byte red, byte green, byte blue) {
 #ifdef ADAFRUIT_NEOPIXEL_H 
   // NeoPixel
   strip.setPixelColor(Pixel, strip.Color(red, green, blue));

 #endif
 #ifndef ADAFRUIT_NEOPIXEL_H 
   // FastLED
   leds[Pixel].r = red;
   leds[Pixel].g = green;
   leds[Pixel].b = blue;
 #endif
}

void setAll(byte red, byte green, byte blue) {
  for(int i = 0; i < 22; i++ ) {
    setPixel(i, red, green, blue); 
  }
  showStrip();
}

void loop(){
  for(int j = 0; j < 3; j++ ) { 
    // Fade IN
    for(int k = 0; k < 256; k++) { 
  checkPiece();
  bluetooth();
  afficheCredit();
  newcred=credit;
  achat();
  erreurAchat();
  resetLumiereBouton();
  //temps();
      switch(j) { 
        case 0: setAll(k,0,0); break;
        case 1: setAll(0,k,0); break;
        case 2: setAll(0,0,k); break;
      }
      showStrip();
      delay(3);
    }
    // Fade OUT
    for(int k = 255; k >= 0; k--) { 
  checkPiece();
  bluetooth();
  afficheCredit();
  newcred=credit;
  achat();
  erreurAchat();
  resetLumiereBouton();
  //temps();
      switch(j) { 
        case 0: setAll(k,0,0); break;
        case 1: setAll(0,k,0); break;
        case 2: setAll(0,0,k); break;
      }
      showStrip();
      delay(3);
    }
  }
}
  

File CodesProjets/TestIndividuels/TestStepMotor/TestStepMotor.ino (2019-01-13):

// Sketch for Arduino and
// 28BYJ-48, using a ULN2003 interface board to drive the stepper.
// Adapted by Mallinson-electrical

//declare variables for the motor pins
int motorPin1 = 2;    // Arduino pin 8 to In 1 on the ULN2003
int motorPin2 = 3;    // Arduino pin 9 to In 2 on the ULN2003
int motorPin3 = 4;   // Arduino pin 10 to In 3 on the ULN2003
int motorPin4 = 5;   // Arduino pin 11 to In 4 on the ULN2003
                      // supply power to + and - from Arduino 5vdc and gnd

int motorSpeed = 1250;  // set speed of 28BYJ-48 stepper,

//max frequency is 100hz, so max speed is 1250

//(100 steps per second 8 pulses per step so 10000 divided by 8)
// 1250 equates to apx 6 seconds per rev
int count = 0;          // count of steps made
int countsperrev = 510; // number of steps per full revolution- actually 509.5 as gear ratio is 63.684:1 apx
int revolutionsCW = 1; // number of revs required clockwise
int revolutionsCCW = 3; // number of revs required counterclockwise
int lookup[8] = {B01001, B00001, B00011, B00010, B00110,B00100,B01100, B01000};
int setTurnsCW = (revolutionsCW * countsperrev);
int setTurnsCCW = (revolutionsCCW * countsperrev);

void setup() {
  //declare the motor pins as outputs
  pinMode(motorPin1, OUTPUT);
  pinMode(motorPin2, OUTPUT);
  pinMode(motorPin3, OUTPUT);
  pinMode(motorPin4, OUTPUT);
  Serial.begin(9600);
}

void loop(){
  if(count < setTurnsCW )
    anticlockwise();
  else if (count == setTurnsCW + setTurnsCCW)
    count = 0;
  else
    clockwise();
  count++;
}


void anticlockwise()
{
  for(int i = 0; i < 8; i++) // 8 pulses
  {
    setOutput(i);
    delayMicroseconds(motorSpeed);
  }
}

void clockwise()
{
  for(int i = 7; i >= 0; i--) // 8 pulses
  {
    setOutput(i);
    delayMicroseconds(motorSpeed);
  }
}

void setOutput(int out)
{
  digitalWrite(motorPin1, bitRead(lookup[out], 0));
  digitalWrite(motorPin2, bitRead(lookup[out], 1));
  digitalWrite(motorPin3, bitRead(lookup[out], 2));
  digitalWrite(motorPin4, bitRead(lookup[out], 3));
}

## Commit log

2018-12-10 Add files via upload
    Rapport de projet de Clement POUEYTO
2019-01-07 Add files via upload
    J'updaterai chaque semaine un nouveau PDF avec les anciens rapports + le nouveau en bas de page.
2019-03-16 Déplacement ancien github sur mon PC
    [Ensemble1.0006.iam, Ensemble1.iam, Pièce-interieur-3.ipt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]
2019-03-16 Ajout 2 : Construction
    [Pièce-interieur-3.ipt, Pièce-moteur-vis.ipt, Pièce-moteur-vis_CPY.ipt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]
